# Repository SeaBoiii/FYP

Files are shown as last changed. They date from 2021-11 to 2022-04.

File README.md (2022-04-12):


<!--
*** Thanks for checking out the Best-README-Template. If you have a suggestion
*** that would make this better, please fork the repo and create a pull request
*** or simply open an issue with the tag "enhancement".
*** Don't forget to give the project a star!
*** Thanks again! Now go create something AMAZING! :D
-->

<!-- PROJECT SHIELDS -->
<!--
*** I'm using markdown "reference style" links for readability.
*** Reference links are enclosed in brackets [ ] instead of parentheses ( ).
*** See the bottom of this document for the declaration of the reference variables
*** for contributors-url, forks-url, etc. This is an optional, concise syntax you may use.
*** https://www.markdownguide.org/basic-syntax/#reference-style-links
-->
[][issues-url]
[][license-url]
[][linkedin-url]

<!-- PROJECT LOGO -->
<br />
<div align="center">
  <a href="https://github.com/SeaBoiii/FYP">
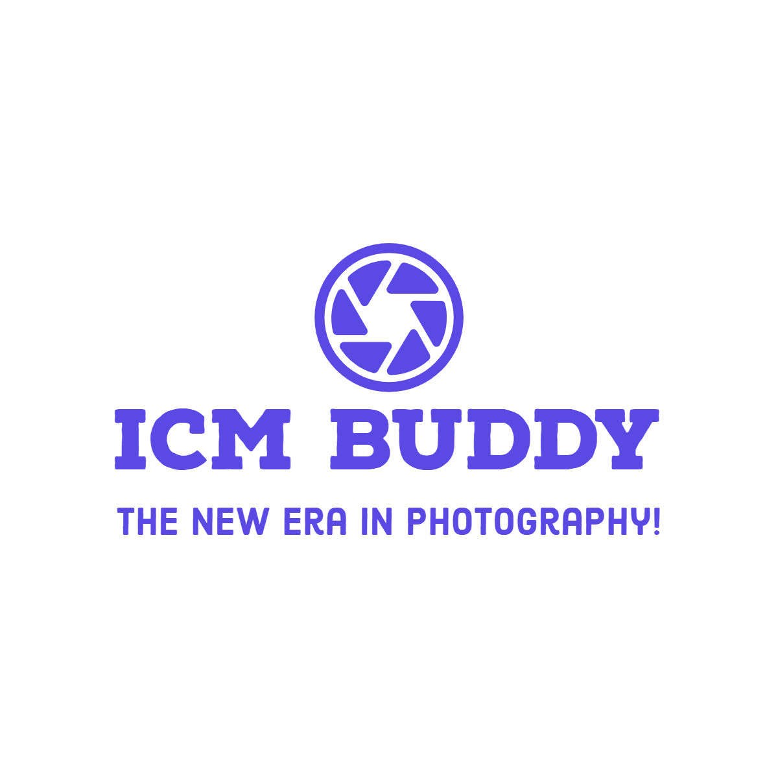
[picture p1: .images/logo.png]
    
  </a>

<h3 align="center">ICM Buddy</h3>

  <p align="center">
    The projective objective is to improve the user experience for experienced and new photographers by providing automation to the camera during the long exposure shoot.
    <br />
    <a href="https://github.com/SeaBoiii/FYP/blob/main/.documents/ICM_Buddy_Final_Report.pdf"><strong>Explore the docs »</strong></a>
    <br />
    <br />
    <a href="https://www.youtube.com/watch?v=y02GOHybE4I">View Demo</a>
    ·
    <a href="https://github.com/SeaBoiii/FYP/issues">Report Bug</a>
    ·
    <a href="https://github.com/SeaBoiii/FYP/issues">Request Feature</a>
  </p>
</div>

<!-- TABLE OF CONTENTS -->
<details>
  <summary>Table of Contents</summary>
  <ol>
    <li>
      <a href="#about-the-project">About The Project</a>
      <ul>
        <li><a href="#built-with">Built With</a></li>
      </ul>
    </li>
    <li>
      <a href="#getting-started">Getting Started</a>
      <ul>
        <li><a href="#prerequisites">Prerequisites</a></li>
        <li><a href="#installation">Installation</a></li>
      </ul>
    </li>
    <li><a href="#usage">Usage</a></li>
    <li><a href="#contributing">Contributing</a></li>
    <li><a href="#contact">Contact</a></li>
    <li><a href="#acknowledgments">Acknowledgments</a></li>
  </ol>
</details>

<!-- ABOUT THE PROJECT -->
## About The Project

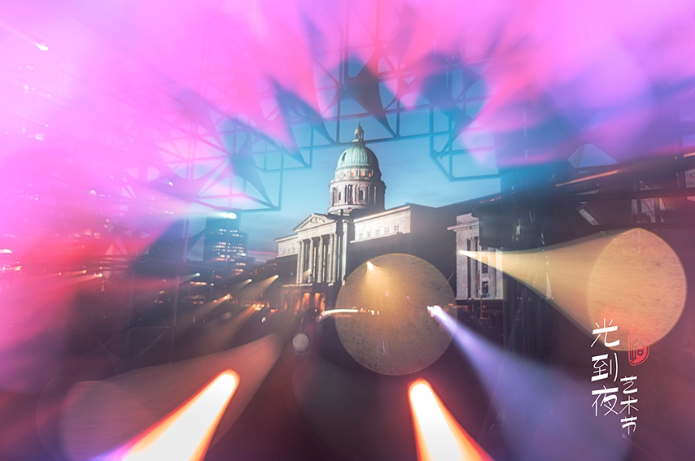
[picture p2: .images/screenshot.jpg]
Product Name Screen Shot


This project aims to improve the consistency of the results obtained from long exposure photography and present new ways to take slow exposure photos by automating the movements of the focus and zoom lens during the shoot. With the pre-sets available in the project, photographers will be able to control the type of resulting images that they can get. 

This project was designed and implemented to produce a system capable in conducting a long exposure shoot with unique sequences to get the optimal long-exposure image results. Through the integration of hardware and software, high precision, and consistency of the DSLR lens rotation could be achieved. This unfolds an endless possibility for both experienced and aspiring photographers in long exposure photography.

From the confident results gathered during testing, this project can produce a consistent and repeatable long exposure image. Paired with the various patterns extended with the custom pattern that user can input, various beautiful long exposed images can be taken.

<p align="right">(<a href="#top">back to top</a>)</p>

### Built With

* [Arduino](https://www.arduino.cc/)

#### Hardware Required
| Name | Quantity | Description |
| --- | ---| ---|
| Arduino Nano | 1 | Small ATmega328 microcontroller 
| TMC2208 Stepper Driver | 2 | Ultra-quiet two-phase stepper motor drive chip, to drive the stepper motors | | |
| NEMA 17 Stepper Motor | 2 | High torque motors to provide precision movements of the lens | | |
| Buzzer | 1 | Sound indicator for users to know before and after a certain sequence is executed | | |
| 1.8’ TFT Display | 1 | Menu selector to control the lens | | |
| Optocoupler P627 | 1 | Isolates the circuit from the camera shutter. Prevents damaging the circuit by high current when the camera shutter is triggered. | | |
| 2.5mm Jack | 1 | Connector for DSLR Camera’s shutter | | |
| 5 Pin Joystick | 1 | Menu movements to select the different options in the menu | | |
| 220 Ω Resistor | 5 | Limit the current to the TFT display | | |
| 1k Ω Resistor | 1 | Limit the current to the Optocoupler | | |
| 100 µF Capacitor | 1 | Prevents accidental damage to the drivers in case of current surge | | |
| 11.1V Lipo Battery | 1 | Power supply for the entire hardware | | |
| DSLR Camera | 1 | For capturing the long exposure images | | |
| Arca-Type compatible DSLR rail | 1 | Motors can be mounted along the rail | | |
| 0.8 Mod Gear Rings | 2 | Rings attached to the focus & zoom lens | | |
| KW12-3 Limit Switch | 4 | [Optional] For further control to the lens | | |

<p align="right">(<a href="#top">back to top</a>)</p>

<!-- GETTING STARTED -->
## Getting Started

The first thing that you will have to do is to create the same setup. The same setup, can be done using the circuit diagram found in the folder. All the hardware required were mentioned above. 

<a href="https://github.com/SeaBoiii/FYP">
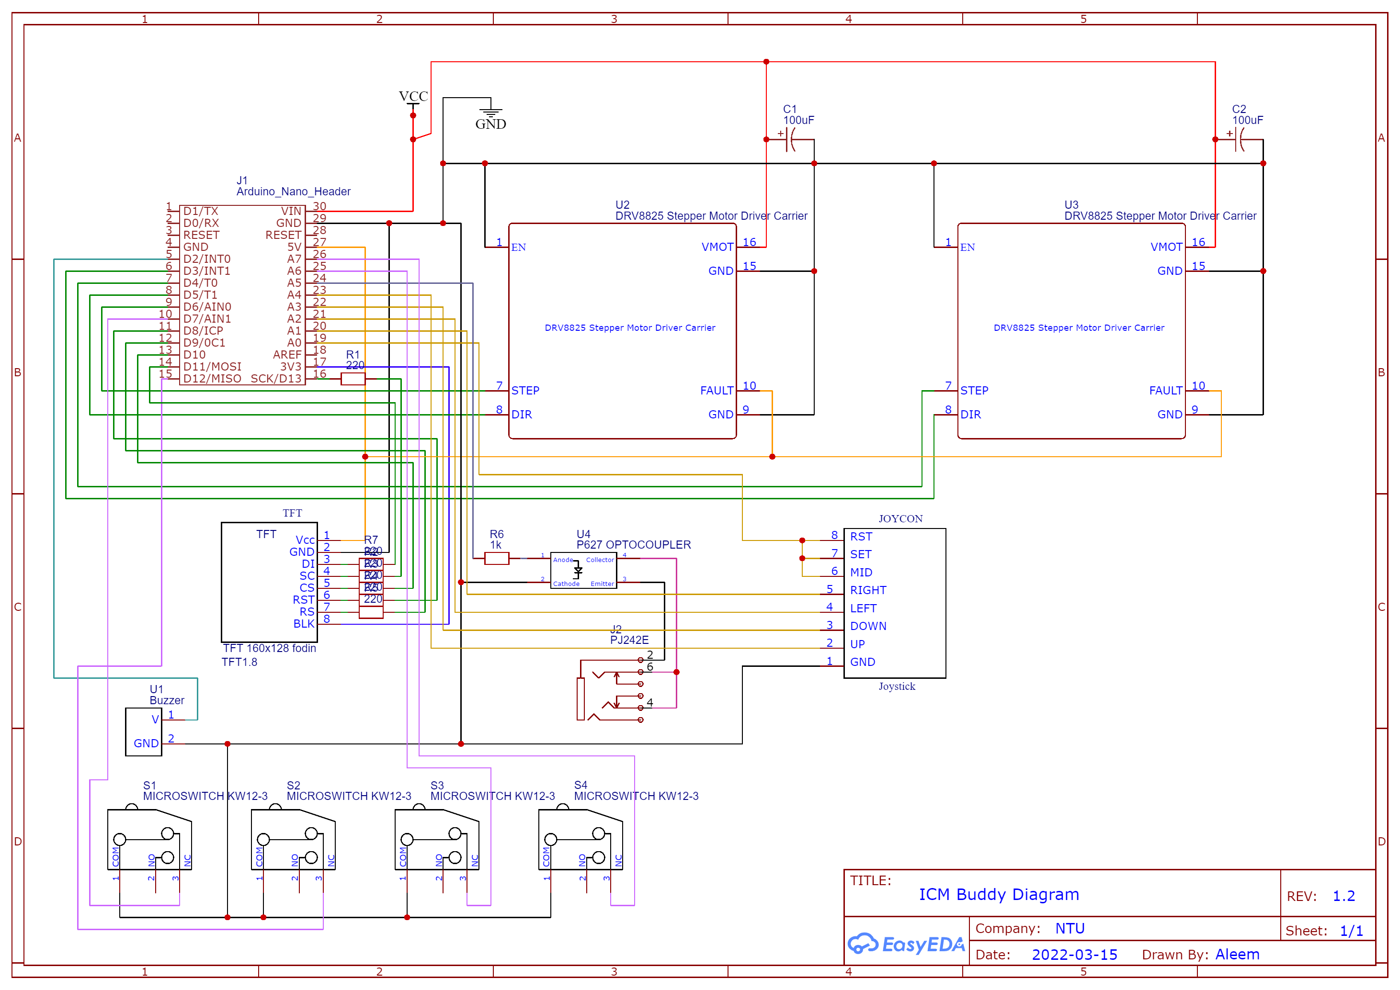
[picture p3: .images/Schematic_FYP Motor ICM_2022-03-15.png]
Schematic Diagram
    
  </a>

If creating the board is to tedious, you can always print a PCB for easier replica of the project. The details of the PCB can be found at [PCB Designs](https://github.com/SeaBoiii/FYP/tree/main/.3D_Designs/PCB).

### Prerequisites

The only software requirement is the Arduino IDE to flash the program to the Arduino. 
* [Arduino](https://www.arduino.cc/en/Guide)

#### Libraries Used

All the libraries used can be downloaded using the IDE or downloaded manually and dropped to the library folder. Only the `AccelStepper` library required to be downloaded while the rest of the library should be pre-installed in the Arduino IDE.
* [AccelStepper](https://www.airspayce.com/mikem/arduino/AccelStepper/)
* [TFT](https://www.arduino.cc/reference/en/libraries/tft/)
* [EEPROM](https://docs.arduino.cc/learn/built-in-libraries/eeprom/)

### Installation

1. Build the prototype first
2. Clone the repo
   ```sh
   git clone https://github.com/SeaBoiii/FYP.git
   ```
3. Install required Arduino libraries
   ```sh
   arduino install AccelStepper
   ```
4. Upload Motor_ICM.ino to the Arduino Microcontroller
   ```sh
   upload Motor_ICM.ino
   ```

<p align="right">(<a href="#top">back to top</a>)</p>

<!-- USAGE EXAMPLES -->
## Usage

The menu of the prototype is very intuitive and navigation can be done smoothly. After attaching the device to your lens, the 1st thing that you would want to do is `calibration`. This allows the motors to remember the marked locations to prevent any damages to the lens. Explore the various menus and patterns available by default to generate interesting long exposure images. 

If the installed patterns are not to your liking, feel free to edit the code and change it or even use the inbuilt custom patterns to build your own custom patterns. Here are more examples of what this device is capable of.

<a href="https://github.com/SeaBoiii/FYP">
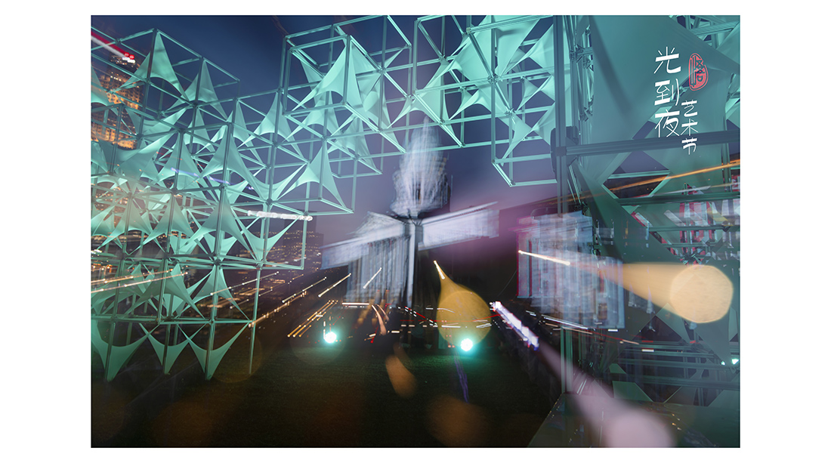
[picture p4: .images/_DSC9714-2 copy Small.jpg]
Using a certain pattern 1
    
</a>

<p align="center">
Using both the movements of the focus and the zoom lens, this shot was taken at the Old Supreme Court building in Singapore.
</p>
  
<a href="https://github.com/SeaBoiii/FYP">
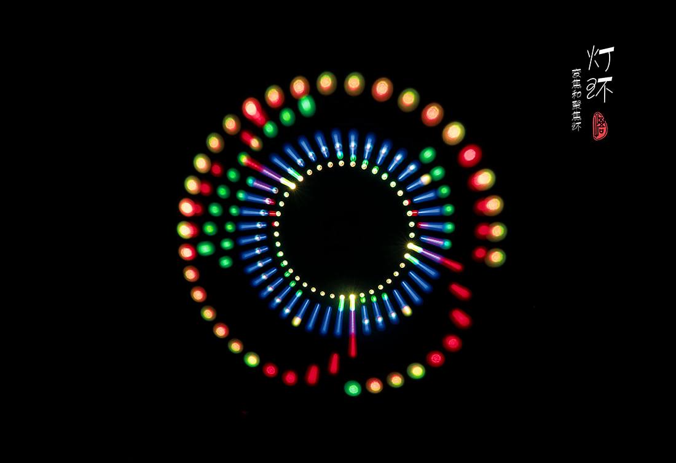
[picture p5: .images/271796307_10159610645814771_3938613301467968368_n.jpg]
Using a certain pattern 2
    
</a>

<p align="center">
Again, both the focus and zoom lens were used to create a circular motion effect of lights. 
</p>
  
<a href="https://github.com/SeaBoiii/FYP">
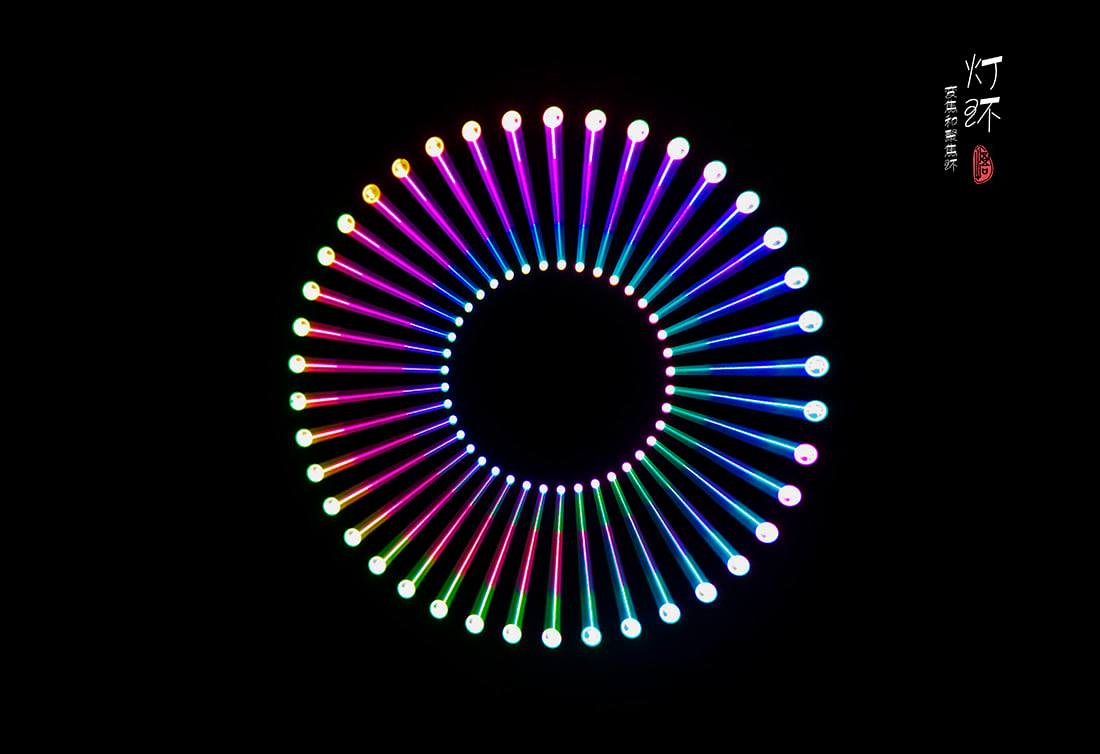
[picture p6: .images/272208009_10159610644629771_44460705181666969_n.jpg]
Using a certain pattern 3
    
</a>

<p align="center">
Only the zoom lens were moved here to create a tunnel vision look.
</p>
  
_For more examples, please refer to the [Documentation](https://github.com/SeaBoiii/FYP/blob/main/.documents/ICM_Buddy_Final_Report.pdf)_

<p align="right">(<a href="#top">back to top</a>)</p>

<!-- CONTRIBUTING -->
## Contributing

Contributions are what make the open source community such an amazing place to learn, inspire, and create. Any contributions you make are **greatly appreciated**.

If you have a suggestion that would make this better, please fork the repo and create a pull request. You can also simply open an issue with the tag "enhancement".
Don't forget to give the project a star! Thanks again!

1. Fork the Project
2. Create your Feature Branch (`git checkout -b feature/AmazingFeature`)
3. Commit your Changes (`git commit -m 'Add some AmazingFeature'`)
4. Push to the Branch (`git push origin feature/AmazingFeature`)
5. Open a Pull Request

<p align="right">(<a href="#top">back to top</a>)</p>

<!-- CONTACT -->
## Contact

Project Link: [https://github.com/SeaBoiii/FYP](https://github.com/SeaBoiii/FYP)

	




<p align="right">(<a href="#top">back to top</a>)</p>

<!-- ACKNOWLEDGMENTS -->
## Acknowledgments

* A/P Chia - My FYP mentor, someone who helped me throughout the whole project
* Auntie @ SimLim Tower - For providing any extra hardware required for my own testings

<p align="right">(<a href="#top">back to top</a>)</p>

<!-- MARKDOWN LINKS & IMAGES -->
<!-- https://www.markdownguide.org/basic-syntax/#reference-style-links -->
[contributors-shield]: https://img.shields.io/github/contributors/SeaBoiii/FYP.svg?style=for-the-badge
[contributors-url]: https://github.com/SeaBoiii/FYP/graphs/contributors
[forks-shield]: https://img.shields.io/github/forks/SeaBoiii/FYP.svg?style=for-the-badge
[forks-url]: https://github.com/SeaBoiii/FYP/network/members
[stars-shield]: https://img.shields.io/github/stars/SeaBoiii/FYP.svg?style=for-the-badge
[stars-url]: https://github.com/SeaBoiii/FYP/stargazers
[issues-shield]: https://img.shields.io/github/issues/SeaBoiii/FYP.svg?style=for-the-badge
[issues-url]: https://github.com/SeaBoiii/FYP/issues
[license-shield]: https://img.shields.io/github/license/SeaBoiii/FYP.svg?style=for-the-badge
[license-url]: https://github.com/SeaBoiii/FYP/blob/master/LICENSE.txt
[linkedin-shield]: https://img.shields.io/badge/-LinkedIn-black.svg?style=for-the-badge&logo=linkedin&colorB=555
[linkedin-url]: https://linkedin.com/in/a1e3m
[product-screenshot]: .images/screenshot.jpg

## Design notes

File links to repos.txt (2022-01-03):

http://www.airspayce.com/mikem/arduino/AccelStepper/classAccelStepper.html
https://www.electronics-lab.com/project/using-st7735-1-8-color-tft-display-arduino/
https://learn.adafruit.com/1-8-tft-display/breakout-wiring-and-test
https://github.com/XarkLabs/PDQ_GFX_Libs

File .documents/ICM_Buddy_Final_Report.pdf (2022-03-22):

School of Computer Science and Engineering

## Final Year Project

## Final Report

## SCSE21-0384: ICM Buddy – Zoom/Focus Assist Tool

Supervisor: A/P Chia Liang Tien

Examiner: Ast/P Lin Shang-Wei

Submitted by: Aleem Siddique Bin Abdul Jamal

Matriculation Number: U1821548E

## NANYANG TECHNOLOGICAL

## UNIVERSITY

# SCSE21-0384: ICM Buddy – Zoom/Focus Assist Tool

## Submitted in Partial Fulfilment of the Requirements for the Degree of

## Bachelor of Computer Engineering of the Nanyang Technological

## University

By

## ALEEM SIDDIQUE ABDUL JAMAL

## Abstract

Long exposure photography is a technique of capturing an image for extended periods of time

to get unique moments, in moving lights photography. There are few commercialised kits

related to long exposure photography sold in the market. And most of these kits are not easily

customisable, or any available automated pre-sets pre-installed. Long exposure photography

can be very tedious to set up since a lot of knowledge of moving the zoom and focus lens during

the shoot will give varying result. Though long exposure shoots can be a fun experience

available to all ages, it requires a lot of time and precision to get the image they want.

This project aims to improve and extend the functionality relating to long exposure

photography that involves the movements of the zoom and focus lens during the exposure

period. The focus of the project is to engineer a prototype capable of bringing automation to

the DSLR cameras during the long exposure shoots by swivelling the zoom and focus lens

utilising motors.

Long exposure photography can be achieved easily with the integration of hardware and

software on Arduino used in this project.

## Acknowledgement

I would like to thank my supervisor, A/P Chia Liang Tien for his guidance and support

throughout the entire course of this final year project. His extreme knowledge in hardware and

his advice has helped me progress through the project without much hiccups.

I would also like to thank the lab attendants from the Software Project Labs for their assistance

in loaning equipment especially the soldering equipment during the soldering process of this

project.

Lastly, I want to thank my friends for their support and suggestions to improve especially the

software part of the project.

## Table of Contents

## Table of Figures

## List of Tables

## List of Abbreviations and Symbols

Abbreviation/Symbols | Description
DSLR | Digital Single Lens Reflex
ISO | International Organization for Standardization
GUI | Graphical User Interface
UI | User Interface
PCB | Printed Circuit Board
TFT | Thin Film Transistor
NEMA | National Electrical Manufacturers Association
3D | Three-Dimensional
LCD | Liquid Crystal Display
CAD | Computer-Aided Design
POV | Point of View
mm | Millimetre, unit measurement for lengths
Ω | Ohm, unit measurement for resistor
µF | Micro farad, unit of measurement for capacitor
° | Degree, unit of measurement for angle

## 1. Introduction

1.1 Background

Long exposure photography, also known as slow exposure, is one of the many types of DSLR

photography. Long Exposure photography is usually use by photographers to capture objects

in motion or static objects with a moving background for long periods of time [1].

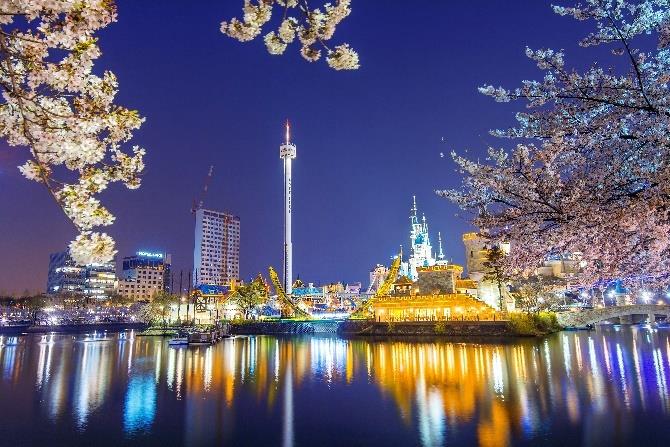
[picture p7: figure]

Figure 1: Long exposure image of traffic [2] | Figure 2: Long exposure image of lights at night [3]

Both process of photography requires time in scouting the area, setting up the equipment as

well as multiple tries to get the desired image. A lot of calculations are also necessary in terms

of the camera settings such as the shutter speed, the ISO, and others [4]. Furthermore, humans

are inconsistent, and this will result in extra time needed to get a consistent result that

photographers are satisfied [5]. The experimentation required during a long exposure shoot is

extremely tedious and there is no straightforward approach available to get pleasurable photos.

This applies to not only experienced photographers but even new aspiring photographers who

wants to learn about long exposure photography will stay away due to the exhausting process

and inconsistent results.

1.2 Project Objective

This project aims to improve the consistency of the results obtained from long exposure

photography and present new ways to take slow exposure photos by automating the movements

of the focus and zoom lens during the shoot. With the pre-sets available in the project,

photographers will be able to control the type of resulting images that they can get. The

projective objective is to improve the user experience for experienced and new photographers

by providing automation to the camera during the long exposure shoot.

1.3 Project Scope

The followings are the scope of the project:

1. Research on long exposure photography, for objects in motion as well as static objects.
2. Research on available motor types to turn the camera lens.
3. Build a prototype (hardware) to control the lens through Arduino
a. Decide on the motor & Arduino to be used for the project
b. Have a display & joystick to efficiently control the different lens, zoom & focus

lens.

c. Code (software) on the Arduino to integrate the hardware together
4. Implement functionalities for the Arduino
a. Create different pre-sets or ways to control the movement of the lenses.
b. Effortlessly allow users to get a long exposure image with a click of a button

and a simple GUI.

## 2. Literature Review

2.1 Long Exposure Photography

Long exposure photography is a type of photography art in capturing an image where stationary

element are sharp while moving elements are smeared. Photographers normally use exposure

photography to capture a certain view like the stars. The main settings for long exposure shots

are the shutter speed, ISO, and the aperture of the DSLR camera [6].

2.1.1 Setting Up

The set-up for a long exposure shoot is simple. Other than the camera settings that requires to

be experimented, a lot of scouting is required in finding a great area to work in. Furthermore,

the use of a tripod is important for a good exposure photo as it keeps the DSLR camera from

moving around like from strong winds, during the shoot.

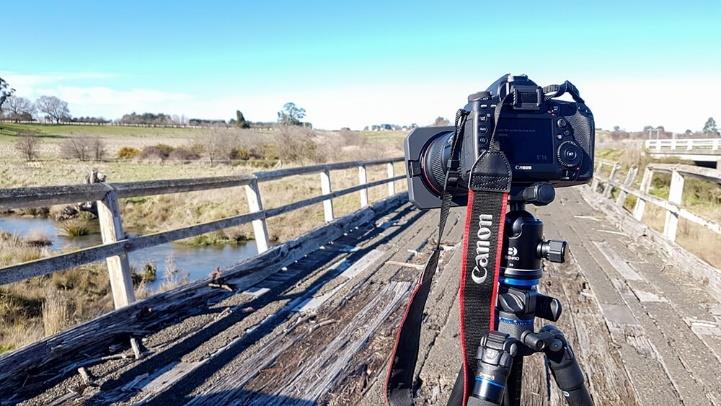
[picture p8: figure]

Figure 3: A setup of a long exposure shoot [7]

After applying the necessary camera settings, the photographer than starts the slow exposure

photograph by pressing the shutter. After the shutter speed set, the DSLR camera will close the

shutter and a long-exposed image will be shown.

2.1.2 The ‘Standard’ Procedure

Ordinarily, long exposure photography involves the DSLR camera being still, and the lens

should not move during the exposure. The lens is normally related to the sharpness of the

image, and disrupting the setup during an exposure shoot, will affect it. However, there are

instances where moving the lens during an exposure will get a particular type of effect. Quoted

by Joe McNally, “Moving the lens during the shoot may seem like a dangerous thing but it can

be kind of a fun thing to do.” [8] By rotating the lens during an exposure, many different types

of outcomes can occur which will be further explored in this project.

2.1.3 Camera Settings

The main camera setting that affect long exposure photography are mainly shutter speed.

Normally, during a long exposure photography session, only the shutter speed setting is

tweaked while the ISO and aperture remains untouched.

Shutter Speed

Shutter speed refers to the time for the camera shutter to stay open and expose the DSLR

camera sensor to light [9]. For long exposure photography, this setting is normally set to a low

shutter speed to capture more details and changes to the light.

Shutter Speed | Photo Clarity
Fast | Darker picture and less blur
Slow | Brighter picture but more blur

Table 1: Relationship between shutter speed and photo clarity

2.2 Follow Focus Gears

The follow focus gears were created to have finer controls over the DSLR focus adjustments.

This prevents the photographer from focusing to the wrong subject. Follow focus is normally

used in filmmaking with film cameras as it helps the operator to be more efficient and precise.

Figure 4: Fotga’s DP500II2 follow focus unit [10]

Though their usage was meant to be used in videos for accurate focus control, the possibility

of rotating the lens can be applied elsewhere, in the example of long exposure photography.

By rotating both the zoom and the focus lens, photographers can get a whole new dimension

in long exposure photography.

## 3. Project Planning

3.1 Material/Equipment Resources (Hardware)

The hardware resources used in this project are shown in Table 1.

Name | Quantity | Description
Arduino Nano | 1 | Small ATmega328 microcontroller
TMC2208 Stepper Driver | 2 | Ultra-quiet two-phase stepper motor drive chip, to drive the stepper motors
NEMA 17 Stepper Motor | 2 | High torque motors to provide precision movements of the lens
Buzzer | 1 | Sound indicator for users to know before and after a certain sequence is executed
1.8’ TFT Display | 1 | Menu selector to control the lens
Optocoupler P627 | 1 | Isolates the circuit from the camera shutter. Prevents damaging the circuit by high current when the camera shutter is triggered.
2.5mm Jack | 1 | Connector for DSLR Camera’s shutter
5 Pin Joystick | 1 | Menu movements to select the different options in the menu
220 Ω Resistor | 5 | Limit the current to the TFT display
1k Ω Resistor | 1 | Limit the current to the Optocoupler
100 µF Capacitor | 1 | Prevents accidental damage to the drivers in case of current surge
11.1V Lipo Battery | 1 | Power supply for the entire hardware
DSLR Camera | 1 | For capturing the long exposure images
Arca-Type compatible DSLR rail | 1 | Motors can be mounted along the rail
0.8 Mod Gear Rings | 2 | Rings attached to the focus & zoom lens
KW12-3 Limit Switch | 4 | [Optional] For further control to the lens

Table 2: Hardware Resources

The connection guide for the hardware can be seen in Appendix A.

3.2 Material/Equipment Resources (Software)

Name | Description
Arduino IDE | Official IDE for Arduino microcontroller software development
AccelStepper Library | Arduino Library by Mike McCauley maintained by Patrick Wasp to control the motor drivers
TFT Library | Arduino Library that enables communication with the Arduino TFT LCD screen
SPI Library | Arduino Library that enables communication with SPI devices
Program Space Utilities | Arduino Library for interfacing with the flash memory of the Arduino
EEPROM Library | Arduino Library for interfacing with the memory of the Arduino
OpenSCAD | A 3D CAD software to create 3D objects for 3D printing
EasyEDA | Software used for PCB designing and circuit diagram creation

Table 3: Software Resources

3.3 Project Process Model

This project follows the linear-sequential life cycle model or approach. The project is separated

into small parts such as motor movements phase, GUI phase, assessed before integrating

together during the testing phase of the model. This ensures tasks are easily arranged and

rigorously evaluated before proceeding to the next phase [11]. Overall, ensuring the project

development to be completed on time and well documented.

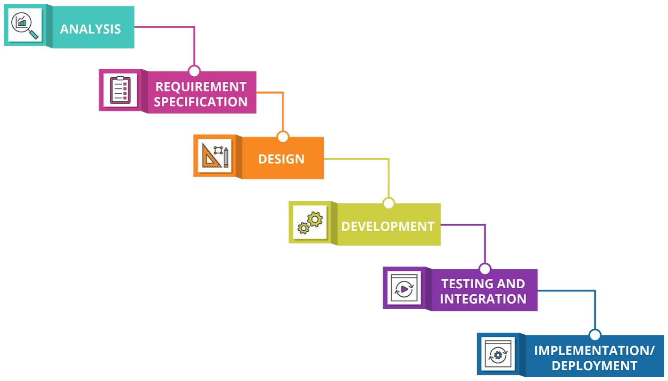
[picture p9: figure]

Figure 5: Waterfall Model [12]

3.4 Project Schedule

The initial project’s timeline is shown below.

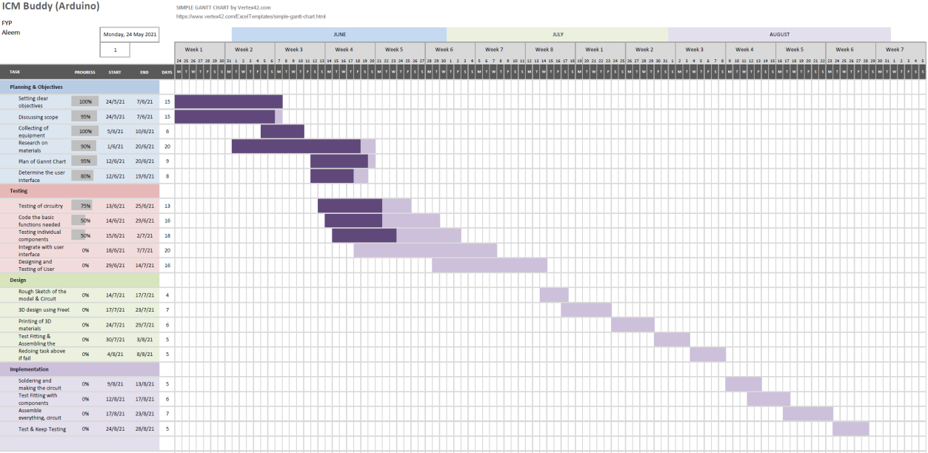
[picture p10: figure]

Figure 6: Initial Gantt Chart

Using the model mentioned in 3.3 Project Process Model, this was the initial deadlines for the

separate phases from the Waterfall Model approach. However, due to some errors and

insufficient research done, the project deviated from the original deadline. This will be further

discussed in (insert heading). The project’s updated timeline is shown in Table 3.

Task Description | Start Date | End Date | Duration (Days)
Discussing scope | 24/5/2021 | 7/6/2021 | 15
Research on long-exposure photography | 1/6/2021 | 20/6/2021 | 20
Research on different motors | 1/6/2021 | 20/6/2021 | 20
Collecting of equipment | 5/6/2021 | 10/6/2021 | 6
Testing of individual components (Circuitry) | 21/6/2021 | 10/7/2021 | 19
Testing of individual components (Software) | 11/7/2021 | 25/7/2021 | 14
3D Design of components required (gears, bases, case, etc.) | 26/7/2021 | 31/7/2021 | 5
Printing of 3D components | 31/7/2021 | 3/8/2021 | 3
Integrating the individual components together | 4/8/2021 | 10/8/2021 | 7
Test fitting and assembling the circuitry | 11/8/2021 | 13/8/2021 | 3

Testing of the integrated module | 14/8/2021 | 18/8/2021 | 5
Testing failed which results in repeating the tasks again as there is a change in the motor used | 19/8/2021 | 7/9/2021 | 20
Integrating and evaluating the integrated module again | 8/9/2021 | 16/9/2021 | 8
Testing failed again, which results in more research needed and a change of hardware again | 17/9/2021 | 27/9/2021 | 10
Revision and Examination | 28/9/2021 | 9/10/2021 | 12
Update & print 3D designs to combat the previous failed testing | 10/10/2021 | 23/10/2021 | 13
Redo the circuitry (hardware) components & testing of integrated module | 24/10/2021 | 13/11/2021 | 21
Revision and Examination | 16/12/2021 | 5/12/2021 | 15
Testing of integrated module | 7/12/2021 | 21/12/2021 | 14
Improvements to GUI | 22/12/2021 | 6/1/2022 | 16
Improvements to code stability | 7/1/2022 | 21/1/2022 | 14
Documentation of code | 22/1/2022 | 25/1/2022 | 4
PCB designing | 26/1/2022 | 30/1/2022 | 5
Improvements to 3D designed components to improve overall stability | 1/2/2022 | 10/2/2022 | 11
Tidying of code | 11/2/2022 | 26/2/2022 | 15
Revision and Examination | 1/3/2022 | 12/3/2022 | 12
PCB printing & soldering of components to PCB | 7/3/2022 | 14/3/2022 | 7
Final Year Project Report | 5/3/2022 | 21/3/2022 | 17
Revision and Examination | 19/4/2022 | 7/4/2022 | 15
Oral Presentation | 10/5/2022 | 10/5/2022 | 1

Table 4: Project's Updated Timeline

## 4. Design Documentation

4.1 Design

Two separate designs with the same functionality were prototyped for this project. Both circuits

use the same microcontroller, the “Arduino Nano” supporting the basic functionalities of

Arduino SOC.

Figure 7: Arduino Nano used for the project [13]

The core components of the two designs were the 3D Printed components such as gears & the

motor housing and the type of motor used. The main prototype that this report will be

discussing is the prototype that used stepper motors. The circuit diagram for the main prototype

can be found in Appendix A. Figure 8 highlighted the whole setup excluding the DSLR camera

that was to be mounted on the Arca-Type compatible DSLR rail.

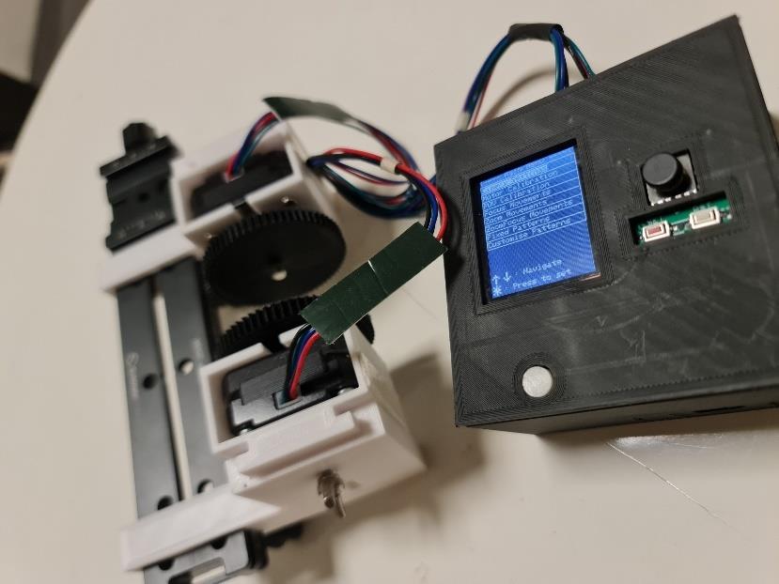
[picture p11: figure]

Figure 8: Setup using Stepper Motors

The prototype that used servo motors was an additional add-on to experiment whether different

motors would vary the movement of the lens. The circuit diagram for the servo motor prototype

can be found in Appendix B.

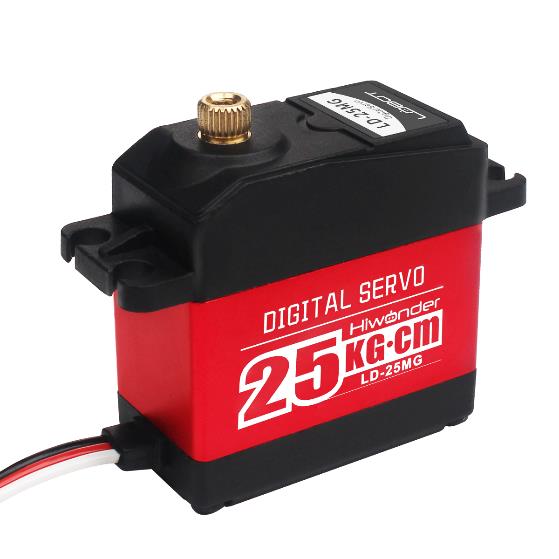
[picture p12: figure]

Figure 9: Hiwonder 25kg Servo Motor used

in the servo-based prototype [14]

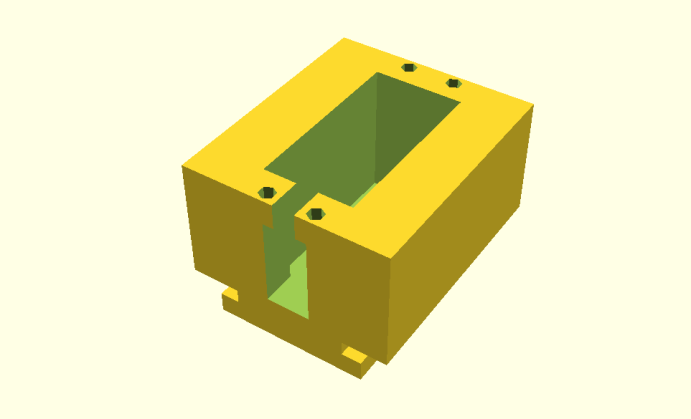
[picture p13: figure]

Figure 10: 3D CAD of the motor housing used for the servo

motors

With the different motors used for both prototypes, this resulted various changes to the 3D

components used since there is a change of dimension for the motor housings & gears.

Other than hardware components, an important research factor that I had to keep in mind during

the designing process was torque. Torque is “a force that causes something to rotate,” as quoted

from Cambridge Dictionary [15]. In this project, a certain amount of torque is required for the

motor to be able to rotate the lens. The variables that determining factors for torque in this

project were the size of gears, the type & size of motor used and the rigidity of the 3D printed

motor mounts.

4.1.1 3D CAD components

The 3D printed components were one of the key components for the project. The measurements

had to be precise, especially the incisions for the screw holes, the T-Slot track, down to less

than a millimetre in precision. The main 3D components that were necessary for the prototype

to function were the T-Slot base, the gears as well as the motor housing. No 3D printed part

for the lens were necessary as there were already plenty of aftermarket choices. These gear

rings will only be needed if the lens lacks a 0.8 module gear to rotate it.

Figure 11: The gear rings used that were attached to the zoom & focus part of the lens

Due to the nature of 3D designing, a lot of pre-sketching of the designs were required to have

a gist of how the 3D object would look like. In addition, 3D printing the components took

plenty of time, combined with the availability of 1 3D printer, courtesy of my Professor, Prof

Chia. Hence, some of the 3D printings were printed by external vendors.

Figure 12: Sketches of the 3D components with measurements

The main software that I used during the 3D CAD objects was OpenSCAD, a script-based

CAD software.

4.1.1.1 T-Slot Base Mount

The design ideology behind the requirement of a T-Slot was the need of an adjustable height

requirement for the motor due to the assorted sizes of available DSLR lens. The T-Slot

functioned as a means of secure for the height of the motor housing to be adjusted.

However, standardised, T-Slots had a very much complex design and to integrate it to the

project, it would be too tedious and time consuming. Therefore, a much simpler design was

needed to provide the same functionality as the traditional T-Slots, the rail like movement as

well as the means of securement. Unlike traditional T-Slot rails, also called OpenBeam, where

it has 4 T-slots available, the design only required one, and a simpler T-shape is needed rather

than the complex trapezium shape from most standardised rails.

Figure 14: Standardised/Traditional T-Slot rail [16]

Screw to secure the
motor housing in
place to a certain
height

T-Slot rail for
the height of
the motor to be
adjustable

Figure 13: The motor housing secured to the T-Slot base

As for the base of the T-Slot, it was designed as an Arca-Type compatible mount, where it can

slide onto any slides that are Arca-Type compatible. Depending on the length of the lens,

different length of the slides is required for the base mount to be fitly secured to the gear rings

on the lens. A lot of iterations of the base mount was required due to the inexperience of 3D

modelling in addition to the strength testing requirement to keep the motor in place when it

was rotating.

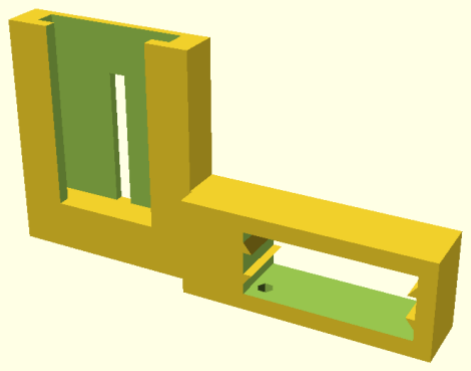
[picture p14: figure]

Figure 15: 3D render of the final iteration of the base mount

Since OpenSCAD is a script-based software, the 3D design of the base mount was not as

tiresome and not including any complex shapes made the process simpler. A code snippet can

be seen below.

module t_slot_beam(t_length, t_thickness) { slot_length = t_length;
slot_thickness = t_thickness; padded_width = mount_width+thickness*2;

difference() {
// stuff to build up
union() {
cube([padded_width, slot_thickness, slot_length]); }
// things to cut out (The T-Slot shaped) t_slot_length = 3;
t_slot_width = 15+20;
t_slot_thickness = 6+20;

translate([padded_width/2-(t_slot_thickness/2),0, 0]) cube([t_slot_thickness, t_slot_length, slot_length]);

translate([padded_width/2-(t_slot_width/2),t_slot_length, 0])
cube([t_slot_width, thickness+3, slot_length]);

translate([padded_width/2-(4/2),t_slot_length+thickness+3,slot_length/2-padded_width/2]) cube([4,2,slot_length-10.5]);
}
}

Figure 16: Code snippet of creating a T-Slot

As seen from the code snippet, to render the 3D object, it was with a simple function call. The

length and thickness of the T-Slot can be adjusted easily by changing the required parameters.

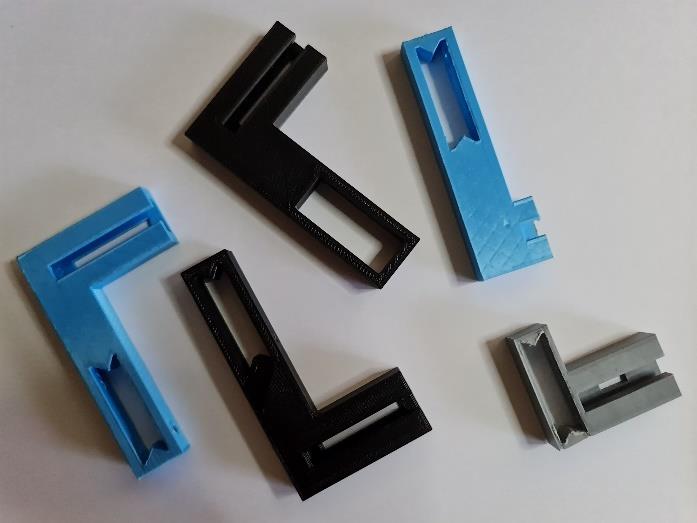
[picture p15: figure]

Figure 17: Different iterations of the base mount

Even then, a lot of effort was required when evaluating the bases to keep the motor in place

during rotation along with being sturdy. Changes to the thickness, the T-Slot size were required

to get the ideal amount of rigidity and sturdiness to prevent the motor from shaking during the

lens rotation.

4.1.1.2 Gears

Gears were also the main components of the entire system. The gears were used to turn the lens

of the DSLR camera. Through research, the size of the gears was important as they determine

the overall torque of the motors, as mentioned previously. The 3D models for the gears were

made with the use of a library created by Thingiverse user eleotlecram. It had a simple GUI to

generate & render the gears.

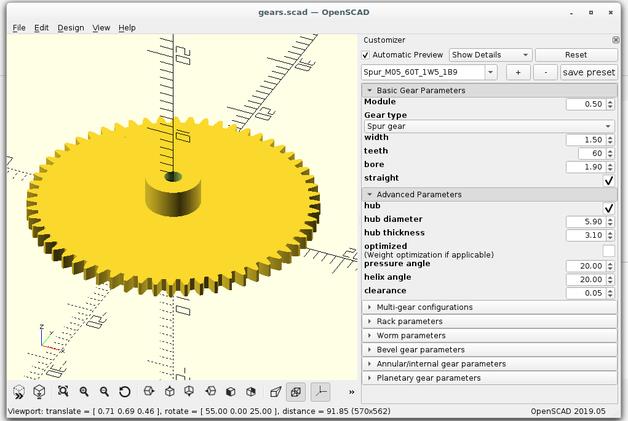
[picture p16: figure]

Figure 18: Gear library used with an intuitive customizer

The type of gear used was the basic 0.8 module spur gears; most DSLR gear rings are 0.8

module as described then. The only variable changed was the number of teeth of the gear (also

corresponds to the size of the gear). The relationship between the number of teeth of a gear and

the torque of the motor as well as the maximum degree of rotation of the lens.

Number of teeth of gear | Torque of motor | Degree of rotation of lens
More (Bigger gear) | Greatly reduced | Increased
Less (Smaller gear) | Increased | Reduced

Table 5: Relationship of the size of gear

Therefore, consideration towards the size of gear was considered to balance between the torque

and the degree of rotation. Most importantly, the size of the gear had to be slightly bigger than

the size of the motor housing to be able to rotate freely.

4.1.1.3 Motor Housing

The design for the motor housing was simple as the components for the housing were just the

motor encasing with a T-Slot attach to it. With the T-Slot, the motor housing would be able to

slide on the T-Slot rail on the base mount. Furthermore, the libraries made by 3D modellers

were available especially for stepper motors. The library that I used was called “Customizable

Stepper Motor Mount for OpenBeam,” which was made by ccox from Thingiverse.com. The

default motor mount was made for OpenBeam rails as shown below.

Figure 19: NEMA 17 motor mount for OpenBeam [17]

The author provided adjustable mounts from NEMA 8 to NEMA 42 motors, two of which were

used for this project: NEMA 8 & NEMA 17 motors. I had to make a few slight changes to the

model, such as covered up all the sides of the motor as well as attached the T-Slot to the back.

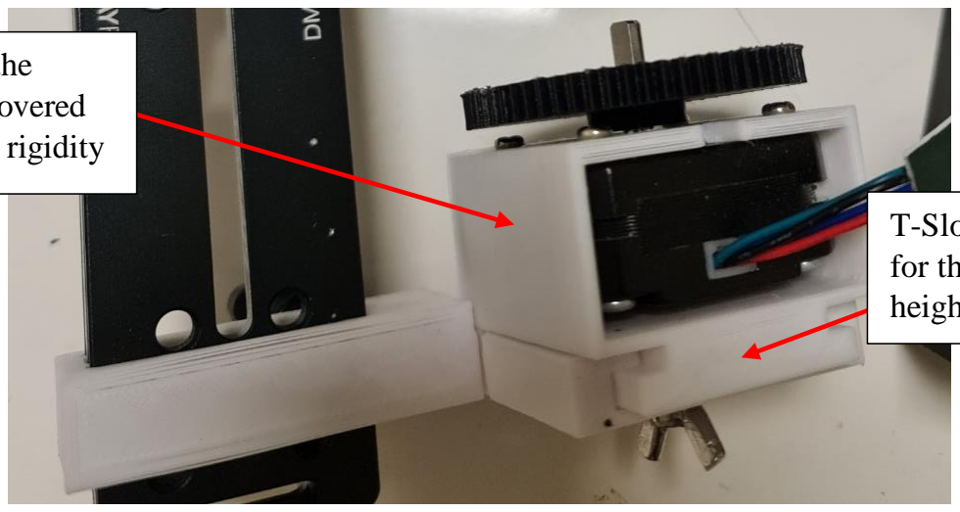
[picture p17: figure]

Figure 20: A complete 3D printed setup; the motor housing, gear & base mount

The sides of the
motor were covered
up to provide rigidity

T-Slot attached
for the adjustable
height of motor

For the servo motors, the online libraries available either were using the smaller type of servo

motors or they did not fit to the design I envisioned. Therefore, I created the servo motor mount

from scratch on OpenSCAD. The requirements for the mount: the same T-Slot as the stepper

motor mounts for hot-swappable using the same base mount & as thin in the width as possible.

difference() {
union() { | The basic cubes required for
// the base as well as the flaps | the servo motor mount
translate([0,-(padded_motor_width/4),0]) cube([padded_length,padded_motor_width,servo_height]); translate([servo_length+thickness,-(padded_motor_width/4),0]) cube([protuding_length,padded_motor_width,servo_height]); translate([-protuding_length+thickness,-(padded_motor_width/4),0]) cube([protuding_length,padded_motor_width,servo_height]);
//t slot | The same T-Slot used for stepper motor mount
xtra = 11.5;
translate([-xtra/2,(padded_width-t_slot_thickness)/2,-(t_slot_length)])
cube([padded_length+xtra,t_slot_thickness,t_slot_length]);

translate([-xtra/2, (padded_width-t_slot_width)/2, -(t_slot_length+thickness+2+0.7)]) cube([padded_length+xtra,t_slot_width,thickness+2+0.7]);
}
// **** stuff to be removed **** | Cutting a cuboid for the servo
// servo motor | motor to reside in
translate([thickness,thickness,thickness-5]) cube([servo_length,servo_width,servo_height+5]);
…

Figure 21: Code Snippet of creating the servo motor mount

There were few changes required for the motor mounts as they stayed the same throughout the

project, other than the need to change the T-Slot when the 3D components required more

rigidity to hold the torque of the motors.

4.2 Motors

For this project, two types of motors were experimented to rotate the lens, the stepper motor &

the servo motor. There were advantages and disadvantages of using either motor. Additionally,

each motor had their own considerations to follow. A list of compiled comparison between the

two types of motor can be seen in Table 6.

Stepper Motor | Servo Motor
Precision | Higher Precision – The chances of the stepper motor missing are low. | Lower Precision – The chances of the servo motor missing are higher under load.
Position Feedback | No Feedback – The stepper motor has no feature for it to know it is current position. | Feature present – Since it uses a sensor for position feedback [18], the servo motor could correct itself if it missed a step. However, this can be a problem for the project as the motor may rotate unexpectedly to correct itself in a middle of a shoot, affecting the image taken.
Torque | 4.5kg.cm | 25kg.cm
Speed of rotation | Slower | Faster
Degree of rotation | Infinite | 180° (In the case of the servo motors used for the project)
Requires a driver? | Yes | No

Table 6: Comparing features between stepper and servo motors

As seen from the table above, both motors have their strengths and weaknesses. However, the

main motor that was used for the project with its own custom PCB was the stepper motors.

4.2.1 Stepper Motor

Two models of the stepper motors, NEMA 8 and NEMA 17 stepper motors were experimented

and assessed. I started off with the smaller NEMA 8 motor before progressing to the much

larger NEMA 17 motor.

4.2.1.1 NEMA 8 Motor

NEMA 8 motors were chosen during the pre-testing phase due to the sheer small size of the

motor. Since the components had to fit the small area underneath or beside the camera.

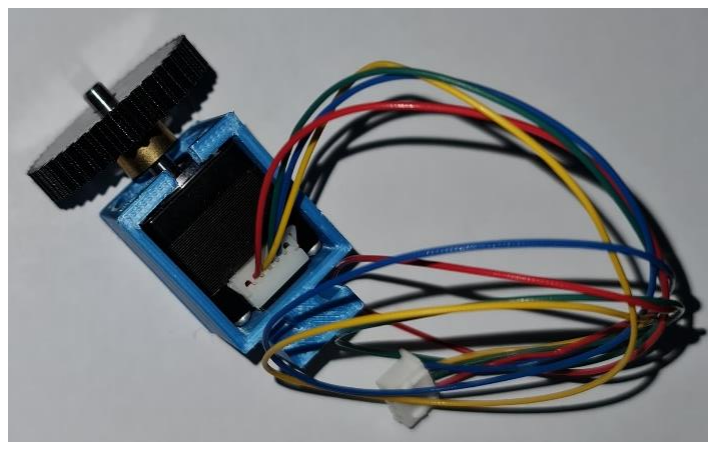
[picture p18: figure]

Figure 22: Small NEMA 8 stepper motor

However, due to the sheer size of the stepper motor, the torque of the motor was not enough to

rotate the DSLR lens, and a different motor had to be considered.

4.2.1.2 NEMA 17 Motor

Stepper motors have different lengths available for the same NEMA typed motor. In the case

of NEMA 17, there were an abundance of lengths to choose from. The “standard” length of a

NEMA 17 motor is 39mm in length. Nonetheless, this length was too big and too heavy to be

test fitted on the prototype. Therefore, a thinner NEMA 17 motor was selected and used.

Figure 23: Standard size of NEMA 17 [19] | Figure 24: NEMA 17 motor used for the project [19]

4.2.1.3 Stepper Drivers

To drive the stepper motors, a stepper driver was required. A stepper motor driver can manage

continuous rotation with precise position control [20]. Paired with a microcontroller, the driver

can rotate the stepper motors with a step and direction input. More of this will be covered in

The order of the display is as follow:

1. A countdown screen is displayed before the start of a sequence followed by a beep of

the buzzer.

2. A display of information will be displayed to the user about the current motor status.
3. If the motor must go back to its previous location, the user will be informed by the

display.

4. At the end of the sequence, a beep will be heard, signalling the end of the motor

movements.

4.3.2 Motor Control.

Two types of stepper motor drivers were evaluated, the more common A4988 stepper driver as

well as the TMC2208 driver. A comparison between the two drivers can be seen in the table

below

Figure 25: A4988 Driver | Figure 26: TMC2208 Driver
Driver chip: | A4988 | TMC2208/9
Pin Configuration: | Both the drivers have the same pin layout which made the drivers easily interchangeable with one another during testing
Noise: | Very Noisy | Quiet
Heat Generation: | With the small heatsink provided, less heat was produced | Requires a larger heatsink to combat the large amount of heat generated
Torque: | Lesser torque | Higher torque

Table 7: Comparison between the two drivers

Comparing the two drivers, the TMC2208 stepper motor driver was chosen as the final driver

to be used for the project. The quiet noise and the higher torque offsets the negligible heat

generated from the driver. A standard NEMA 17 motor requires 200 steps to rotate one round.

The TMC driver defaults to 1/8 micro stepping which suggests that a total of 8 * 200 = 1600

steps is required for 1 360° rotation.

4.2.2 Servo Motor

The servo motor used had 180° maximum rotation.

Figure 27: Servo motor used for the project [14]

Having a fixed maximum rotation suggested that I had to integrate the different components

together first because I do not have any idea on the maximum rotation for the lens. After

assessing the rotation, I concluded that the maximum rotation for any lens will always be less

than 180°.

Figure 28: The parts of the camera lens [21]

However, this was true for the zoom ring as they have a maximum and minimum rotation. For

the focus ring, some lenses do not have any maximum rotation. This issue unfortunately could

be resolved during the calibration process of the lens.

4.3 Coding/ Implementation

The programming model that was used for this project could follow procedural programming

as the software contains procedures or functions. A simple flowchart of the main loop can be

seen in the figure below.

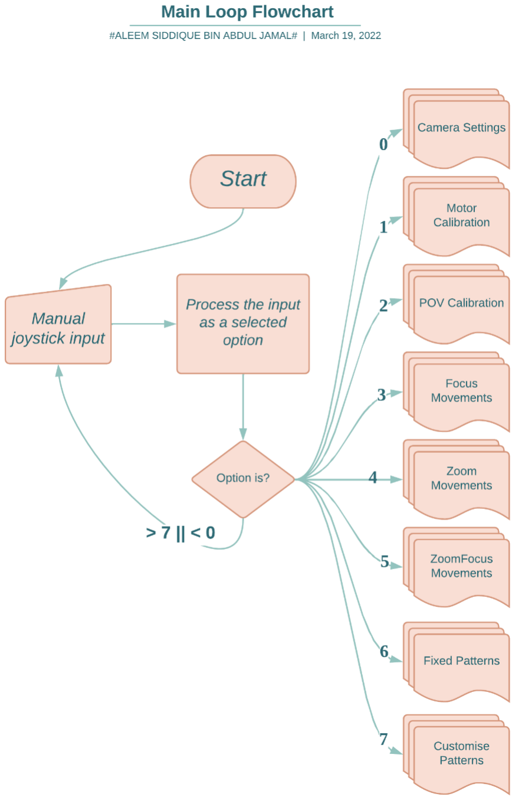
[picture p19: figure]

Figure 29: Flowchart of the main loop

The programming style follows a top-down approach, but I did add some Object-Oriented

principles in the code, which was to ensure that each function in the “separate” file had only

one job to do. Only the interface functions were functions to integrate the distinct functions

from the different files together. A table below to describe the functionalities of each file.

File Name | Task/Role
Motor_ICM.ino (Stepper) Servo_ICM.ino (Servo) | The main Arduino file where all the variables were declared, the pins used, and the setup and loop function.
a_DISPLAY.ino | Functions targeted primarily to the display. The primary functions in this file were the menu and slider function.
b_MOTORCONTROL.ino | Functions involving the stepper driver and stepper motors (for stepper motor setup) or the servo motor themselves. The primary functions in this file were the moving motor and the moving multiple motor function.
c_JOYSTICK.ino | Functions requiring the current user input. Any changes to the joystick movements would update the relevant variables required.
d_INTERFACE.ino | The main integrator. Functions in this file integrated all the three above modules. The functions were customised based on a relevant procedure or movement logic of the motor. If the functions here are insufficient to move a motor in a certain manner, it can easily be added in this file.

Table 8: Functionalities of each file

In a way, the three “module” files function as a library and their files were normally untouched

once done and evaluated. By implementing the code this way, for expendabilities purposes,

only the main Arduino file will need to be touched if other patterns are required. Though, I also

added a way for users to create and customise their own patterns which will be further discussed

in the report.

Some of the global variables are kept in storage to prevent users for redoing some of the

procedures again such as motor calibration or POV calibration.

4.3.1 Display GUI

When a user starts the program, they will be greeted with the main menu screen. The GUI was

coded as intuitive as possible, and instructions were also given for a user to navigate around

the menu. Both prototypes with different motors have the same menu since the overall

functionality remained the same.

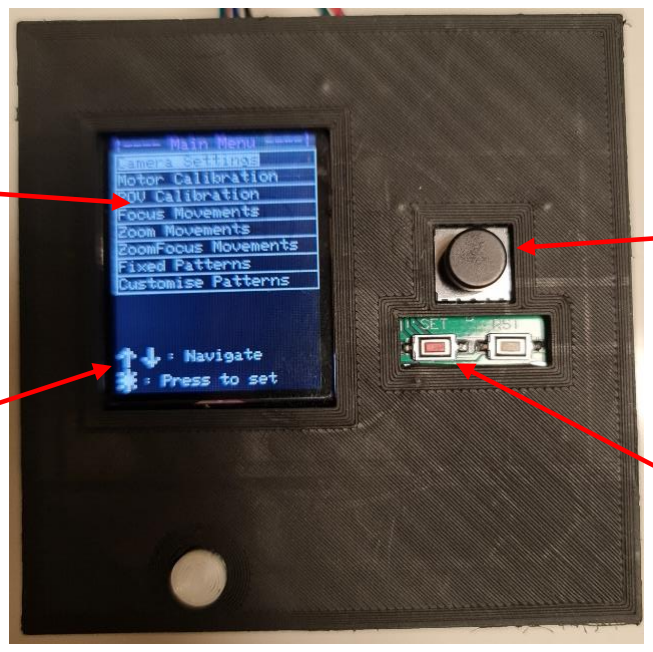
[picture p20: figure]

Figure 30: Main Menu display

There would be a total of eight options in the main menu, of which five of them related to the

motor movements. User would be able to navigate the different options by up & down and

press the select key to select the option chosen. Each option and the functionalities will be

covered. For the implementation of how the UI was done through Arduino, this will be

discussed after explaining the basic GUI that the user will experience.

Navigation keys (Up,
Down, Left, Right)

Select/Set key

Select to current
selected option

Display menu

Navigation
instructions

4.3.1.1 Main Menu GUI

Camera Settings

This was the first option in the main menu. Here, users can swap motor positions. Not all lenses

come with the same Focus and Zoom ring positions. Therefore, a swap motor position here is

necessary for users with different lenses without the need to physically change the hardware

motor wiring.

Figure 31: Camera settings is highlighted and selected

Figure 32: Different settings options

Figure 33: A slider to set the shutter time (the same for motor)

The variables used for the settings was displayed in Figure 32 for users to know the current set

camera settings. In Figure 33, the slider UI was used, and users can set the value by navigating

left and right using the navigation keys. This menu was also the same for the motor movement

time but with a different text.

Camera shutter time refers to the shutter time of the DSLR camera. This does not change the

time of on the camera but must be manually sync to the camera shutter time.

Motor movement time refers to the time needed to execute a sequence. This by default would

always set to -1 to 2 seconds from the shutter time for the DSLR camera to capture the current

scene before the motor movements can happen.

Motor Calibration

Calibration of the motors was needed as the minimum and maximum angle of rotation for the

focus and zoom rings are important during the motor movements.

Figure 34: Motor calibration is selected | Figure 35: Different options in calibration menu

Three options were available to be selected in the calibration menu. Zoom and Focus

calibration and reset all values. Zoom and Focus calibration were straightforward, set the

minimum angle, followed by the maximum angle and this returns the maximum range that the

motor can rotate for the lens. The values here are stored in memory for the Arduino

microcontroller. Users can restart the application/prototype without the need for a recalibration.

However, recalibration will wipe out the values stored, and the new values will be saved

instead.

Figure 36: Calibrate minimum zoom angle | Figure 37: Calibrate maximum zoom angle

Reset the values could be used when changing lens, a quick way to reset the values rather than

recalibrating again.

POV calibration

POV refers to the image that the user wants to capture. A user would want to capture a certain

image by adjusting the zoom and focus of the lens. The calibration is required for the motor to

know the location that it wants to go to or to return after a motor movement sequence is

executed. This ensured that the image was always kept in view at any point of time during the

shoot. The same slider as motor calibration to adjust the appropriate zoom or focus rings.

Figure 38: POV calibration is selected | Figure 39: Adjusting the zoom lens to the desired image

Motor Movements

Focus movements, zoom movements, zoomfocus movements, fixed patterns and customise

patterns all belong to the same hierarchy that was to rotate the motor in a specific way. The

different default patterns can be viewed in Appendix D. For customise patterns however, there

were some differences as it requires users to make their own patterns.

Figure 40: Customise patterns selected

Figure 41: No saved patterns found

Figure 42: Saved pattern available to be executed

Only one pattern could be saved at any point of time and the pattern can have a maximum of

eight sequences. If the pattern is available, user can execute the pattern. Any new pattern

created afterwards will override the previous pattern.

4.3.1.2 Menu UI

The two main UI used for the software is the menu and sliders UI. Regarding the menu UI, it

was split to three parts, a header, a body, and a footer, each were customisable based on the

parameters feed in the function. The code documentation in Figure 43 that was done easily

explained how the menu UI functions.

/**
* ----- MENU ------
* Creates a menu using a string array
* Display which option is being selected *
* [Top of screen] | {Configurable}
* Shutter Speed: __
* Front Motor: ____
* Rear Motor: _____
*
* [Middle of screen]
* |----< Menu Name >----|
* | Option 1
* | Option 2
* | ...
*
* [Bottom of screen]
* < > Move the lens | {Will be dependent on the menu}
* ^v | Select the options
* | o | Select current option
*
* @param array_size | Maximum choices that the menu should have.
* @param string_table[] | Character array of strings to be displayed.
* @param option_selected | Current selected option.
* @param header | Values from -2 to 4, to display varying
headers.
* @param footer | Values from 0 to 2, to display varying footers.
* @param color | uint16_t colors can be used for display.
* @return int | The maximum choices of the menu.
*/
int menu(int array_size, const char *const string_table[],
| | int option_selected, int header=0, int footer=2, uint16_t color=DEEPPINK)

Figure 43: Code snippet of the menu function

Different parameters can be passed to get desired menu on the screen.

string_table[]
is a

character array which requires the title followed by the different option texts: option one, option

two… An example of a menu can be seen in the figure below.

max_option = menu(8, main_menu, option, 0);

An eight-option menu was created with the option selected was highlighted in white. If the

option changes, the menu would update and reflect properly. Users will then know which

option is currently selected visually.

4.3.1.3 Sliders UI

The sliders UI, similarly, to the menu UI also have different customisation available. The slider

function parameters and what each parameter corresponds to can be seen in the code snippet

below.

**
* --- Hotbar Screen ---
* Creates a template for a bar type screen
*
* @param title | Title of the hotbar/screen.
* @param current | Current value.
* @param max_range | Maximum range allowed. (Always start from 0)
* @param current_option | Current option selected. (Only used if `haveBack`
is true)
* @param haveBack | Insert a back button if needed.
* @param header | Values from -2 to 4, to display varying headers.
* @param footer | Values from 0 to 2, to display varying footers.
* @param color | uint16_t colors can be used for display.
* @param updateBar | Only updates certain areas of the hotbar. (Save
Time)
*/
void hotbar(char title[], int current, int max_range,
int current_option=0, bool haveBack=false, int header=0, int footer=3, uint16_t color=WHITE, bool updateBar=false)

Figure 44: Code snippet of hotbar/slider function

The parameter

haveBack=false
referred to an optional back button for user to navigate back

to the previous screen. What parameters correspond to what can be seen in the figure below.

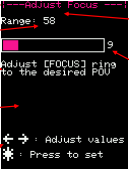
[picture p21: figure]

Figure 45: An example slider screen

The most important parameter for the function is

updateBar
. If the parameter is set to true,

only the current value and the bar of the slider refreshes. As TFT display were slow to refresh,

this was a countermeasure to that.

Title of slider
Header (if needed)
Displays relevant
information if needed

Maximum range
of slider

Current value of the
slider

Footer
Displays navigation
instructions

Slider description

A Back navigation
will be here if needed

4.3.1.4 Motors in Motion UI

Motors in motion UI are a set of screens that will be displayed to the user during a motor

sequence. This was to inform the user of the current task. Paired with a buzzer, the user will be

notified of the start and the end of a motor rotation sequence.

Figure 46: Countdown screen | Figure 47: Moving to the location | Figure 48: Moving back to default

The order of the display is as follow:

5. A countdown screen is displayed before the start of a sequence followed by a beep of

the buzzer.

6. A display of information will be displayed to the user about the current motor status.
7. If the motor must go back to its previous location, the user will be informed by the

display.

8. At the end of the sequence, a beep will be heard, signalling the end of the motor

movements.

4.3.2 Motor Control

Motor control forms the backbone of the software as the controlling of the motors must be done

in these functions. Since the two prototypes using different motors share similar code, the

functions here are different due to the nature of the libraries used.

4.3.2.1 Stepper vs Servo Motors

For the project, I used the “AccelStepper” library to control the drivers and motors for the

stepper motor setup. There were extensive functions available and an easy way for the motors

to remember their current positions. Due to the nature of stepper motors having a lower torque

as compared to servo motors, there was a need to have acceleration to the motor for a smooth

transition. This would prevent the motor from losing additional torque during the rotation

process.

float calcRPM(int steps, float seconds) { return (float)(steps * MS_STEP)/seconds; }

float calcAccel(int steps, float seconds) { float max_speed = calcRPM(steps, seconds); return (float)max_speed / seconds;
}

Figure 49: Code snippet of RPM and acceleration calculations

Also, since there was a timing for the motor to move called ‘motor_time’, the speed calculation

was critical in regulating the time for the motor to complete a fixed rotation. The speed and

acceleration were calculated as shown in Figure 49.

I used the “Servo” library to control the servo motors. Unlike stepper motors, servo motors

remember their current position due to the sensors attached (refer to 4.2 Motors). For stepper

motors, it was based on position coordinates and the library calculates if any negative or

positive movements was required. Furthermore, since the speed for servo motors cannot be

regulated, I had to use delays between each degree angle of rotation.

if (steps_to_move > 0) { // +ve
for (int pos=pos_current; pos<=pos_desired; pos+=1) {
if ((type == 1 && orientation == 0) || (type == 0 && orientation == 1)) { // if rear motor
motor->write(MOTOR_STEPS - (pos + min_pos));
} else {
motor->write(pos + min_pos);
}
delay(toMS((float)shutter_spd/abs(steps_to_move))); }
}
Figure 50: Code snippet of the requirement of a delay

4.3.2.2 Moving singular Motors

Stepper motor

Moving a singular stepper motor was straightforward. From the library, there were only two

functions required to move a motor. Set the position for the stepper motor to move to followed

by the run command in a while loop.

stepper->moveTo(pos_desired * MS_STEP);

//blocking statement
while (stepper->distanceToGo() != 0) { stepper->run();
if(shutter_spd != 0) {
delay(toMS((float)shutter_spd/abs(steps_to_move))); }
}

Figure 51: Code snippet of the moveMotor function

As mentioned earlier, to move the stepper motor to the desired location in a certain time, the

speed of the motor had to change. This was set before the stepper motor was allowed to run.

Servo Motor

Servo motor implementation of moving a motor was less complicated from the library

examples. However, the need to do an extra calculation to decide if the servo motor needed to

go the positive or negative direction made the implementation a little complicated.

int steps_to_move = (pos_desired - pos_current); | Check if the steps to move
| to desired location is
// if +ve, move clockwise | positive or negative
// else -ve, move anti-clockwise
if (shutter_spd != 0) {
if (steps_to_move > 0) { // +ve
for (int pos=pos_current; pos<=pos_desired; pos+=1) { if ((type == 1 && orientation == 0) ||
(type == 0 && orientation == 1)) { // if rear motor motor->write(MOTOR_STEPS - (pos + min_pos));
} else {
motor->write(pos + min_pos);
}
delay(toMS((float)shutter_spd/abs(steps_to_move))); }
}

if (steps_to_move < 0) { // -ve

Figure 52: Code snippet of the direction decider

Selecting the correct motor

In the 4.3.1.1 Main Menu GUI, it mentioned that users can select which motors (the rear or the

front motors) are used for rotating the zoom or focus gears. The implementation on how to

select the correct motor was by using an object pointer and points it to the correct motor that

requires to rotate.

AccelStepper *stepper;
if (type) { | declared | The pointer points to
stepper = orientation ? &front_motor : &rear_motor; | | the correct motor based
} else { | | on set orientation
stepper = orientation ? &rear_motor : &front_motor;
}

An object pointed is

Figure 53: Code snippet of selecting the correct motor to move

4.3.2.3 Moving multiple Motors simultaneously

Moving of multiple motors at the same time was straightforward as it was the same

implementation as singular motors except the need for another run function in the while loop.

while (rear_motor.distanceToGo() != 0 || front_motor.distanceToGo() != 0) {
rear_motor.run(); | Both motors to run. If a motor is done, this function does nothing
} | Delay: Uses average steps to have an ideal delay between the two motors

Condition: waits for both motors to complete their movements

Figure 54: Code snippet on moving multiple motors concurrently

Feeding the right position to go for each motor was simpler as there was not a need for an

object pointer. The values were fed to each individual motor instead depending on the

orientation set.

if (zoom_value == -1) {
rear_position = orientation ? focus_value : zoom_current; front_position = orientation ? zoom_current : focus_value; } else if (focus_value == -1) {
rear_position = orientation ? focus_current : zoom_value; front_position = orientation ? zoom_value : focus_current; } else if (focus_value == -1 && zoom_value == -1) { rear_position = orientation ? focus_current : zoom_current; front_position = orientation ? zoom_current : focus_current;
} else { | The rear and front motors were feed
rear_position = orientation ? focus_value : zoom_value;
front_position = orientation ? zoom_value : focus_value; | with the required movements depending
} | on the orientation of the motors

Figure 55: Code snippet on setting the correct values to the correct motors

4.3.3 Interface Functions

The interface functions combine the functions from separate file, remarkably like the

integration phase of the waterfall model.

4.3.3.1 Calibration

The implementation of calibration for the motors was to get the minimum angle, followed by

the maximum angle and get the range.

zoom range = maximum zoom − minimum zoom

After getting the 3 values required, the minimum angle becomes the absolute minimum

position. For stepper motors, there was a function called setCurrentPos which was able to set

a position relative to the current stepper motor position.

Figure 56: Before setCurrentPos method | Figure 57: After setCurrentPos method

In the example above, the stepper motor sets its current position relative to whatever was

supplied in this case, ‘setCurrentPos(0)’. This suggested that the minimum angle set for the

stepper motor will always be 0.

However, for servo motor, the implementation is slightly different. Since there was not any

method like the ones used in stepper motor, the minimum angle of the servo motor must be

saved. The angle of movements acquired the additional minimum angle during movements.

total angle to move = angle to move + minimum angle

The ‘total angle to move’ was then supplied to the motor to rotate accordingly.

4.3.3.2 Setting a specific distance

There was also a function that allows the user to set a specific distance, this was usually

necessary for custom movements other than the pre-sets available. The backbone of the method

functions similarly to the calibrate function though only 2 values were required, which was the

position to go to. The values can then be supplied to the motor to rotate.

Current
motor angle:
135°

Current
motor angle:
0°

4.3.3.3 Moving motors to a certain distance

The interface function for this integrates the 4.3.1.4 Motors in Motion UI and 4.3.2 Motor

Control. The control of the shutter as well as the buzzer was set here. The sequence to move

the motor to a certain distance are as follow:

1. Users press a certain pattern/sequence to execute.
2. Shutter of the DSLR camera opens and the buzzer starts beeping.
3. The screen starts to display the relevant information to the user while the motor starts

to rotate.

4. Upon the end of the motor movements, shutter of the DSLR camera closes, capturing

the image and the buzzer beeps signalling the end of a sequence.

Controlling the shutter

Shutter control was done simply by using the camera remote shutter release cord connected to

the 2.5mm jack on the board.

Figure 58: A camera remote shutter release cord for Nikon DSLR [22]

Software side, a short pulse of LOW to HIGH was required to toggle the shutter.

void nikonTime() { // Controls the shutter of a Nikon camera digitalWrite(SHUTTER, LOW); // close shutter (fully pressed) delay(20);
digitalWrite(SHUTTER, HIGH);
delay(20);
}
Figure 59: Code snippet of the shutter control function

Buzzer

Controlling the buzzer was done using the inbuilt Arduino library in running any buzzer. The

code can be seen below. Beeps the buzzer for 500ms by default.

void buzz(int delay_ms=500, int freq=1000) {
tone(BUZZER, freq); | // Send freq(Hz) sound signal...
delay(delay_ms); | // ...for delay_ms
noTone(BUZZER); | // Stop sound...
}
Figure 60: Code snipper of the buzzer

4.3.4 Customise Patterns

The implementation of allowing users to create their own patterns was something that I spent

lots of time and was immensely proud of the process.

4.3.2.1 Moving motors from a specified string

The core of the customisation comes from the motor movements. To create custom patterns, I

decided to use strings to store the sequence. Strings can easily be stored in Arduino storage

(more in 4.3.4.2 Setting custom patterns) therefore the string had to be read in a certain format

and execute the instructions embedded in it. Each sequence consisted of 4 aspects with up to 6

characters. An example instruction set can be seen in the table below.

Character position [6] | [0] | [1] | [2] | [3++]
Character option | Z or F | T or F | T or F | Int (0-999)
Representation | Either zoom or focus motor | If the motor needed to go back? | If this is the last sequence in the procedure? | The position of the motor to move to
A full example | ZFF80, FFF40, ZTF18, FTT7

Table 9: An example instruction set of custom patterns

A simple split function was used to separate the string by the comma. Each sequence was then

passed to another function to execute the instruction of the sequence.

void setMotor(char* data, char title[], int custom_itemcount) { bool goBack = false;
if ((data[1] == 'T' || data[1] == 't')) {
goBack = true;
}

bool lastSequence = false;
if ((data[2] == 'T' || data[2] == 't')) { lastSequence = true;
}

if ((data[0] == 'F') || (data[0] == 'f')) {
int steps = strtol(data+3, NULL, 10);
// set focus motor steps to steps
goDist(FOCUS, title, steps, SNOW, goBack, motor_time/custom_itemcount, lastSequence);
}

if ((data[0] == 'Z') || (data[0] == 'z')) {
int steps = strtol(data+3, NULL, 10);
// set zoom motor steps to steps
goDist(ZOOM, title, steps, AZURE, goBack, motor_time/custom_itemcount, lastSequence);
}
}

Checks if the motor has to go back based on the instruction set

Checks if this was
the last sequence

The position to move was passed to the interface function goDist

Figure 61: A code snippet of how the instruction set was read and executed

4.3.4.2 Setting custom patterns

To set a custom pattern, the method is simple for users to use. This was briefly shown in the

Motor Movements section. A flowchart to show the user interaction when creating a new

pattern can be seen below.

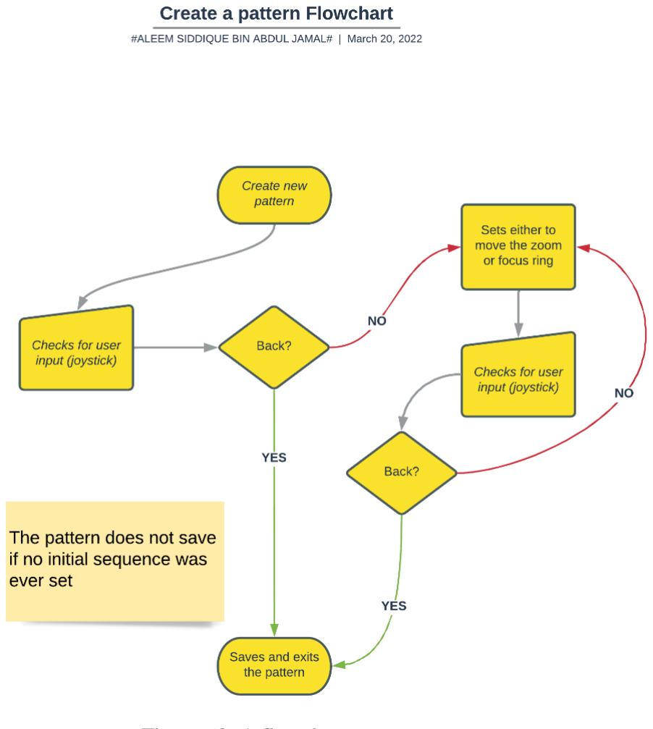
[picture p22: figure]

Figure 62: A flowchart to create a pattern

The pattern will be saved when the user clicks back and executing the pattern/procedure as set

would be possible.

Figure 63: A pattern was successfully saved and can be executed

Creating a new pattern will override the current saved pattern since the microcontroller only

has enough storage to only save 1 array of sequences.

4.4 Integrating with PCB

The project started off on a breadboard before progressing to a PCB board after the hardware

was confirmed. Using EasyEDA online designer tool, I was able to design a PCB and it was

sent to printing. The full PCB board can be viewed in Appendix C.

4.4.1 PCB Designing

The designing process of the PCB started off from the circuit diagram before using the designer

built-in tool to generate a PCB. Thanks to most of the community, most of the hardware used

were available and they were just a drag and paste to the circuit board.

Figure 64: Auto routing tool available on EasyEDA

The PCB wire connection could also be done thanks to the auto routing function of the tool.

However, some tweaks still needed to be done such as thickening the wires and rewire certain

connections.

4.4.2 PCB Assembly

The assembly process of the PCB was done with the help of my professor, Professor Chia. The

hardware required for the PCB was soldered to the PCB and a 3D case was printed to encase

the PCB board along.

Figure 65: A fully assembled PCB board

In the end, the prototype was ready to be extensively evaluated in different kind of conditions

for the long exposure shoot.

Battery was placed
inside the 3D case

Ribbon cables were
used to connect the
display and joystick to
the PCB

An On/Off switch
for easy access

4.4 Integrated Testing

4.4.1 Capturing of objects in motion

For this test, the prototype was setup in a completely pitched black environment other than a

circular RGB light. This RGB light changes as it travels around the loop. The prototype was

evaluated with the help of my FYP mentor, Prof Chia. The type of light used is seen below.

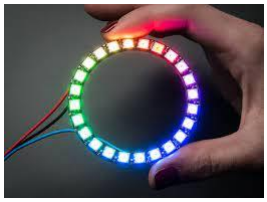
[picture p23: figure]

Figure 66: Circular RGB light used in testing

The 1st sequence used was the zooming to the maximum sequence (see Zoom Movements in

Appendix D). The sequence was to rotate the zoom lens of the DSLR from the current POV to

the maximum range that was set. The result of the photo can be seen below.

Figure 67: The result of using 'zoom to max' [23]

The resulting image was as expected as the lens zoomed in to the RGB light. However, as seen

from the long-exposed image, there are bits of lights with no colours, just white, which suggests

an over exposure.

The next sequence to be used was the ‘zoom to min and focus to max’ pattern (see ZoomFocus

Movements). The sequence rotates both the zoom rings and focus rings at the same time in

opposite direction. The image was to get zoomed out while also get blurry.

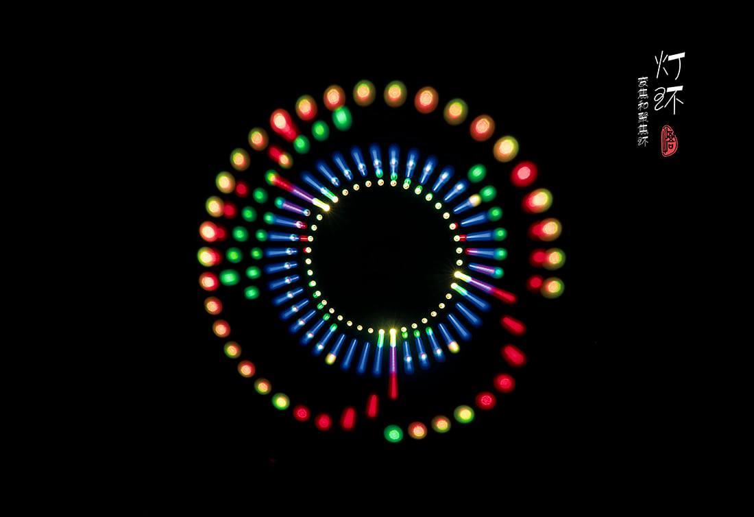
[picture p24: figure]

Figure 68: The result of using 'zoom to min & focus to max' [24]

The resulting long-exposed image looked stunning with the different colours and the blurry

fade out of the image made it a beautiful art piece.

4.4.2 Capturing of static objects

The following testing were done on a building but with colourful lights painting the Old

Singapore Supreme Court Building.

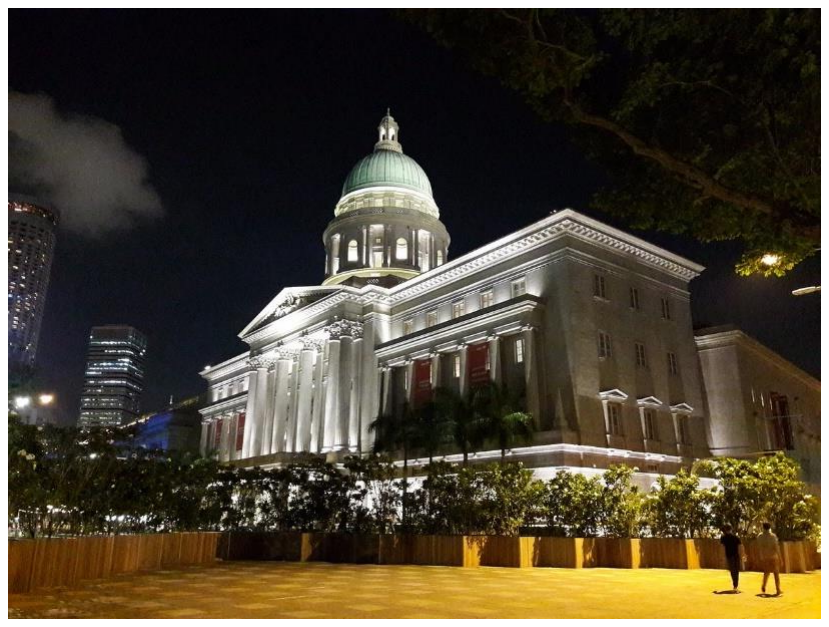
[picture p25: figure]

Figure 69: The Old Supreme Court Building taken without long exposure [25]

The 1

st sequence used for the long exposure shoot was ‘Zoom and Focus to maximum’ (see

ZoomFocus Movements).

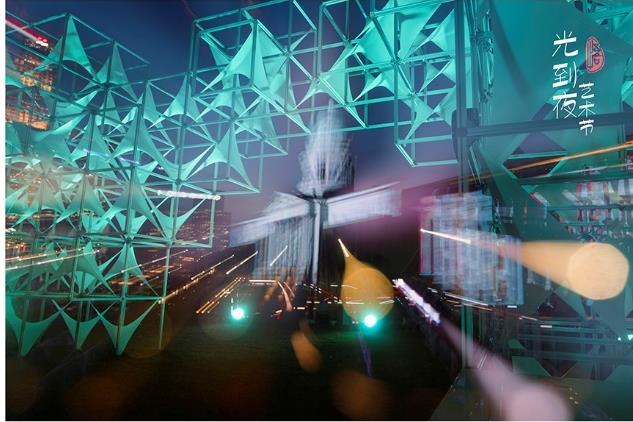
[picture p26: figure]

Figure 70: Old Supreme Building with colourful scaffoldings [26]

The DSLR camera zooms in while also blurring the image resulted in the image above. The

foreground was completely normal, but the background of the Old Supreme Building was

distorted and blurred out.

The next sequence used was the opposite of the sequence used previous, where both the zoom

and focus rings rotates to the minimum. The image gets zoomed out and the foreground gets

blurry.

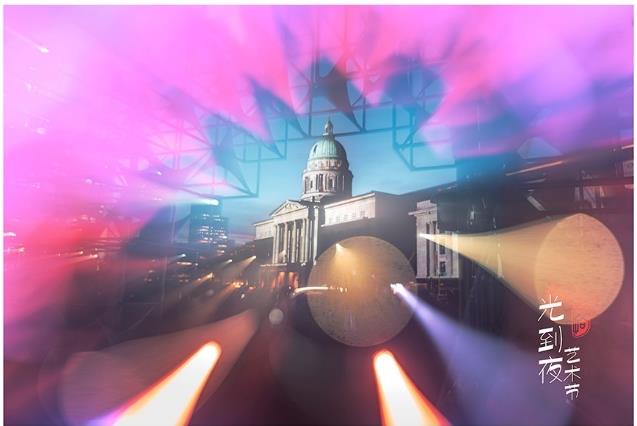
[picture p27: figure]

Figure 71: Old Supreme Court Building painted pink [26]

The images captured of static objects with moving background (in this case, the lights), were

outstanding. Furthermore, all of this were done with a simple push of a button, which was to

select the chosen pattern.

## 5. Challenges and Issues

Even though I was a Computer Engineering student, I had never had any experience with

hardware. Therefore, a lot of hardware was lost due to short circuit or mishandling of the

equipment. However, after reading and learning about the Dos and Don’ts, I was able to avoid

destroying any more hardware.

Also, the lack of knowledge of motors was the main cause to a major setback to the timeline

that I first had in mind. Understanding why the motor could not rotate the DSLR lens. With the

help of online videos to grasp about torque, I was able to change the motor used as well as the

driver resulting in a working motor that could now rotate the lens. It was definitely a huge

success.

The main problem that I had due to the TFT display were the huge amount of program storage

space used in the Arduino Microcontroller. I had many pertaining problems that involves

insufficient storage, and I was required to shorten the code or made it as efficient as possible.

More often than naught, I had to recode the entire portion to make the code function as dynamic

as possible. A total of 3 recode to the entire project had to be done to remove any redundancies

in the code and the approach assisted by following procedural programming.

## 6. Conclusions

To reiterate, this project was designed and implemented to produce a system capable in

conducting a long exposure shoot with unique sequences to get the optimal long-exposure

image results. Through the integration of hardware and software, high precision, and

consistency of the DSLR lens rotation could be achieved. This unfolds an endless possibility

for both experienced and aspiring photographers in long exposure photography.

From the confident results gathered during testing, this project can produce a consistent and

repeatable long exposure image. Paired with the various patterns extended with the custom

pattern that user can input, various beautiful long exposed images can be taken.

Despite the current standings of the project, there are many further optimisations that can be

made. In the PCB, there are connectors for 4 limit switches that can be used to further improve

the calibration of the motors enhancing the system. Furthermore, the project was coded in a

way where future developments can be integrated and added in such as directly controller the

DSLR camera settings itself.

## References

[1] F. Gola, “Long Exposure Photography: A step-by-step guide,” Digital Photography School, [Online]. Available: https://digital-photography-school.com. [Accessed March 2022].
[2] Wirestock, Artist, Traffic with long exposure light trails of cars. [Art]. Freepik.
[3] tawatchai07, Artist, Lotte world amusement park at night and cherry blossom. [Art]. Freepik.
[4] Masterclass, “8 Tips for Shooting Long Exposure Photography,” 8 November 2020. [Online]. Available: https://www.masterclass.com/. [Accessed March 2022].
[5] S. L. Y. &. T. B. Kannappan, “Human consistency evaluation of static video summaries.,” Multimedia Tools and Applications, vol. 78, no. 9, pp. 12281-12306, 2019.
[6] Format Team, “Here’s How To Master The Art Of Long Exposure Photography,” Format Magazine, 21 February 2019. [Online]. Available: https://www.format.com/magazine/resources/photography/long-exposure-photography. [Accessed March 2022].
[7] L. Cole, Artist, Long exposure photography tips. [Art].
[8] Moving Your Lens During Exposure: Photo on the Go with Joe McNally. [Film]. United States of America: Adorama Photography TV, 2014.
[9] B. O. Carroll, “A Comprehensive Beginner’s Guide to Aperture, Shutter Speed, and ISO,” PetaPixel, 25 July 2016. [Online]. Available: https://petapixel.com/aperture-shutter-speed-iso-beginners-guide-photography/. [Accessed March 2022].
[10] S. March, Artist, Seamless Follow Focus Gears. [Art].
[11] J. Waddel, Artist, The Cascading Costs of Waterfall. [Art]. 2019.
[12] S. Lewis, “Waterfall Model,” Tech Target, February 2019. [Online]. Available: https://www.techtarget.com/. [Accessed March 2022].
[13] Arduino, Artist, Arduino Nano. [Art].
[14] Hiwonder, Artist, Hiwonder LD-25MG Strong Torque Digital Servo 25KG Supports Robotic Arm/RC Car/Single Shaft. [Art].
[15] Cambridge, Torque, Cambridge Dictionary, 1995.
[16] E. Hup, Artist, Eng Hup Aluminium Glass Trading. [Art].
[17] ccox, Artist, Customizable Stepper Motor Mount. [Art]. 2017.
[18] D. Sawicz, “Hobby Servo Fundamentals,” 2012.
[19] StepperOnline, Artist, Nema 17 Motors. [Art].

[20] Polulu, “Stepper Motor Drivers,” [Online]. Available: https://www.pololu.com/category/120/stepper-motor-drivers. [Accessed March 2022].
[21] K. McEnaney, Boost Your Photography: Learn Your DSLR, Amazon Kindle, 2013.
[22] Neewer, Artist, Neewer 2.5mm-N1 Off Camera Remote Shutter Release Connecting Cord Cable for Nikon. [Art].
[23] A. C. L. Tien, Artist, Circular Light Zooming to the Max. [Art]. Nanyang Technological University, 2021.
[24] A. C. L. Tien, Artist, The finest lights. [Art]. Nanyang Technological University, 2021.
[25] S. Views, Artist, Photo of City Hall Building. [Art]. 2016.
[26] A. C. L. Tien, Artist, [Art]. Nanyang Technological University, 2022.

## Appendix A

Circuit Diagram of Project (Stepper Motors)

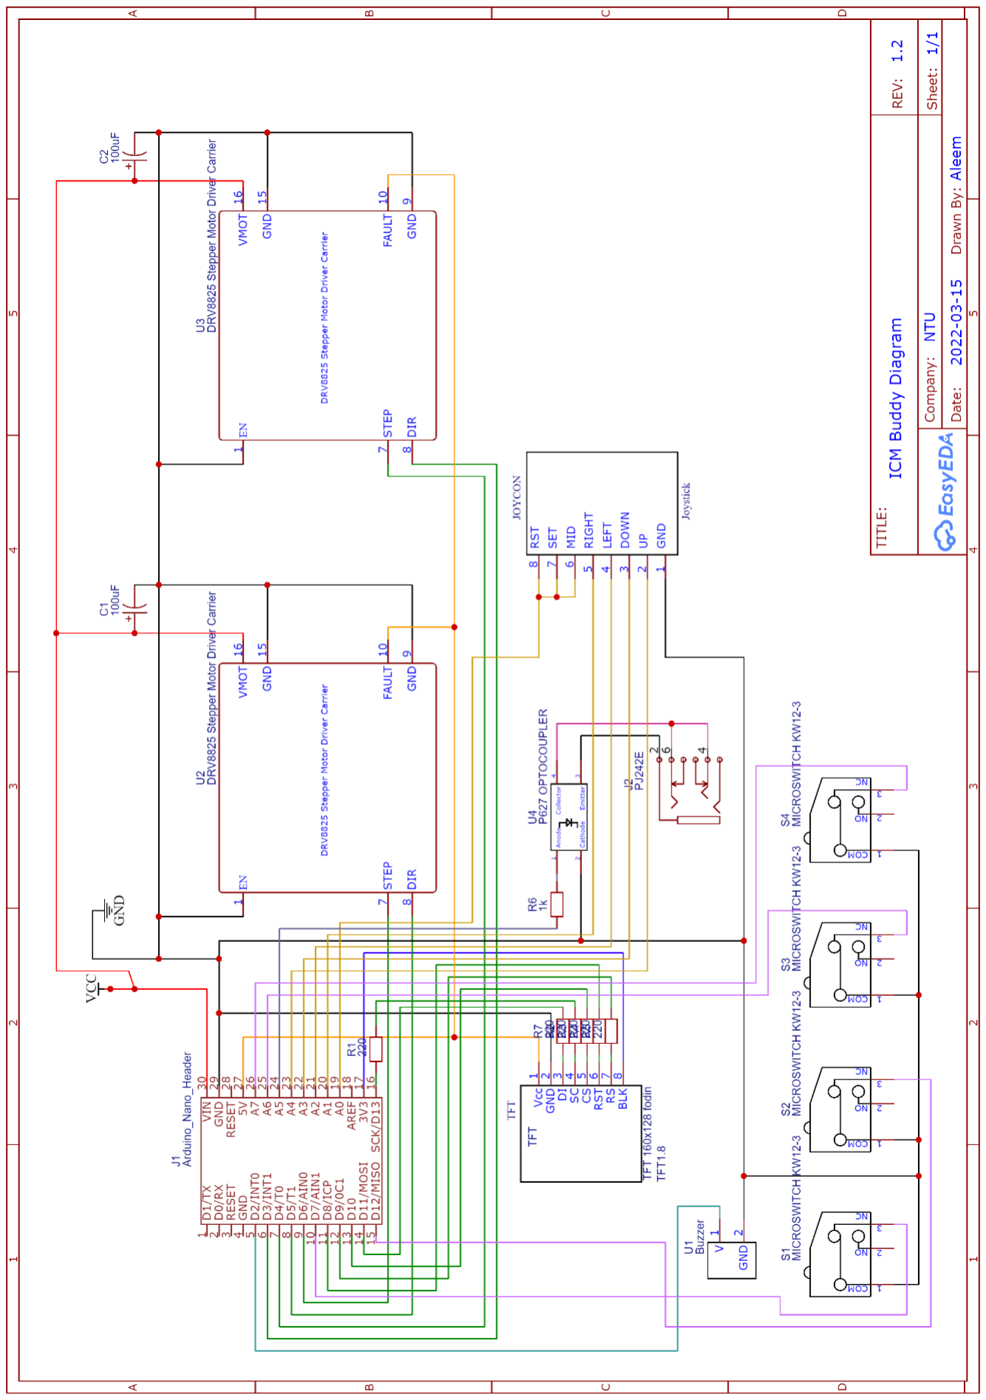
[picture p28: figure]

Figure 72: Circuit Diagram of Project (Stepper Motors)

## Appendix B

Circuit Diagram of Project (Servo Motors)

Figure 73: Circuit Diagram of project (Servo Motors)

## Appendix C

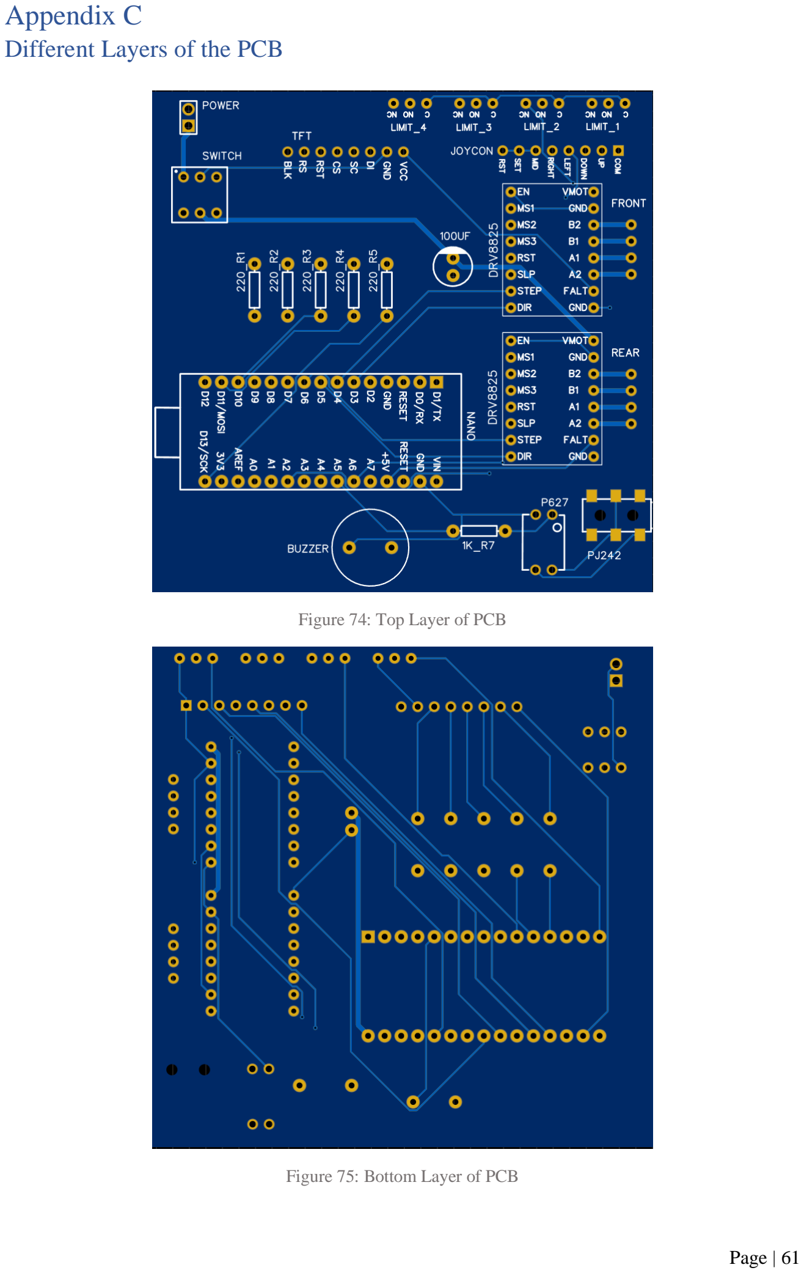
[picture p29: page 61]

Different Layers of the PCB

Figure 74: Top Layer of PCB

Figure 75: Bottom Layer of PCB

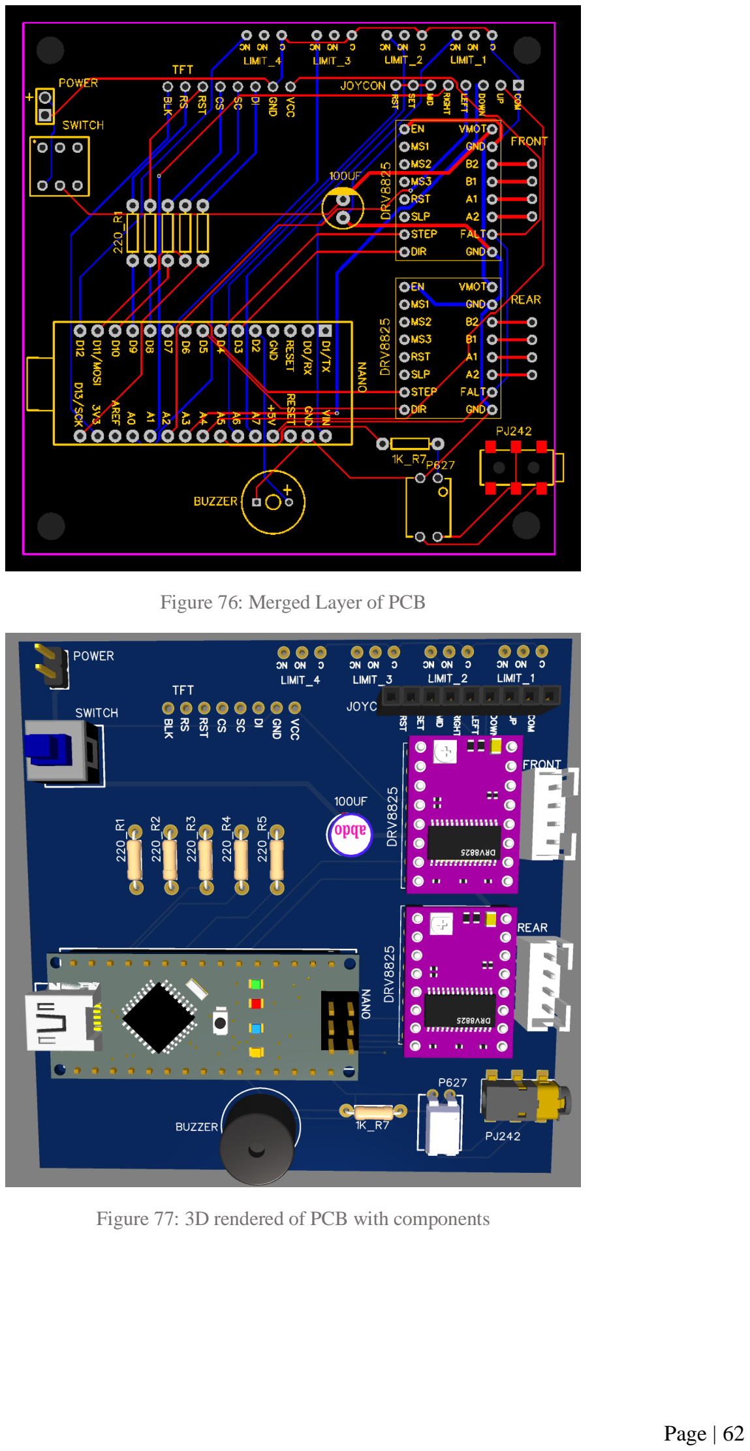
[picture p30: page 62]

Figure 76: Merged Layer of PCB

Figure 77: 3D rendered of PCB with components

## Appendix D

Available Pre-sets

Focus Movements

Figure 78: Focus Movements is selected | Figure 79: The different patterns available

Zoom Movements

Figure 80: Zoom Movements is selected | Figure 81: The different patterns available

ZoomFocus Movements

Figure 82: ZoomFocus Movements is selected | Figure 83: The different patterns available

Fixed Patterns

Figure 84: Fixed Patterns is selected | Figure 85: The different patterns available

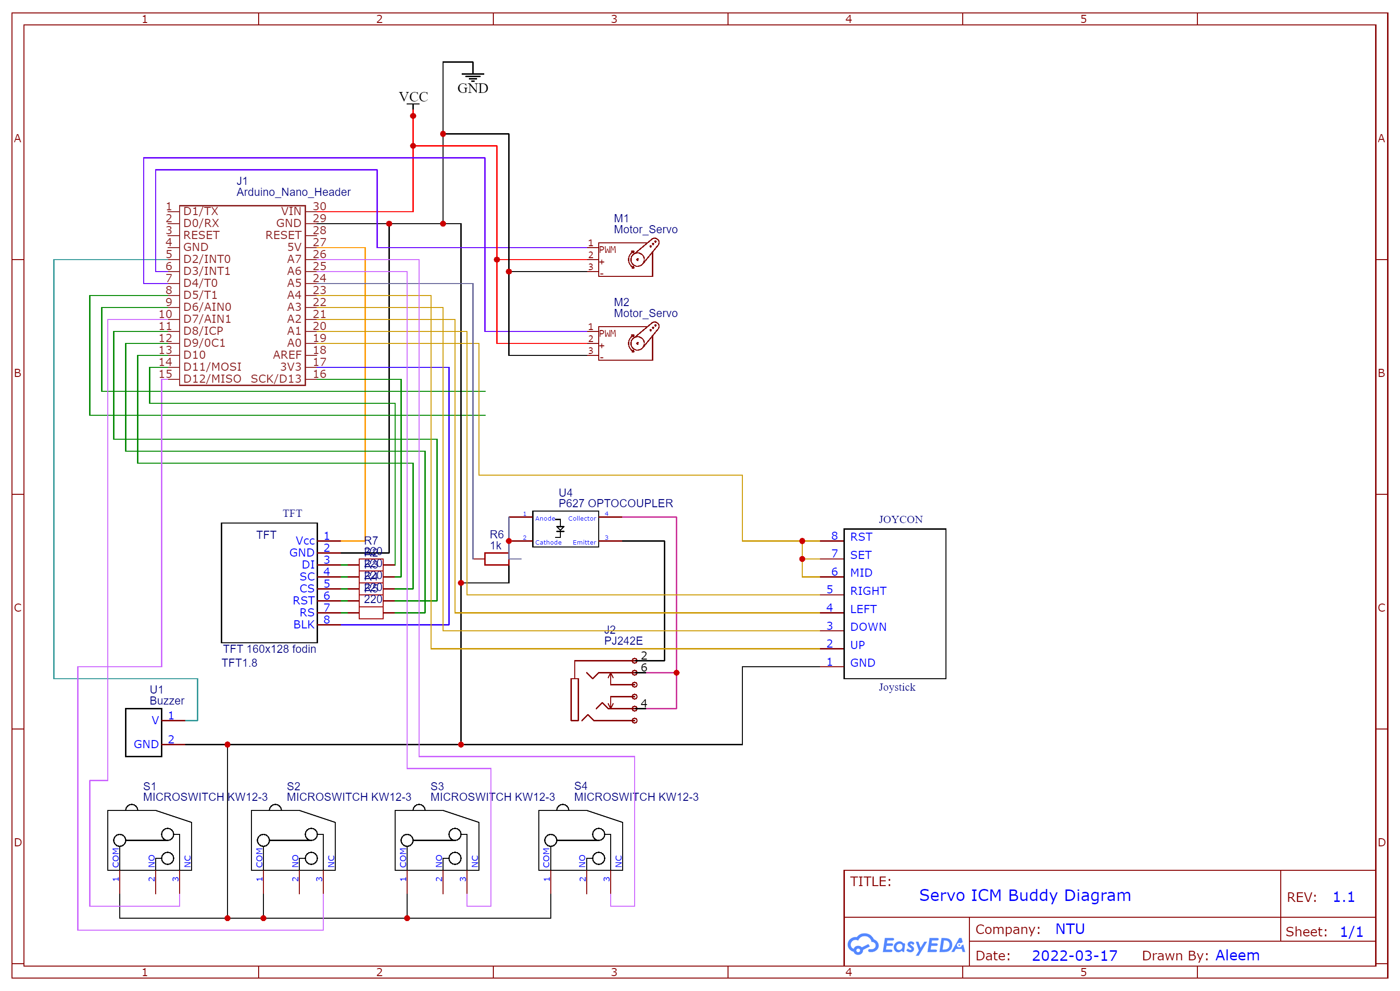
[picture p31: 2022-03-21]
.images/Schematic_FYP Motor ICM_2022-03-17.png

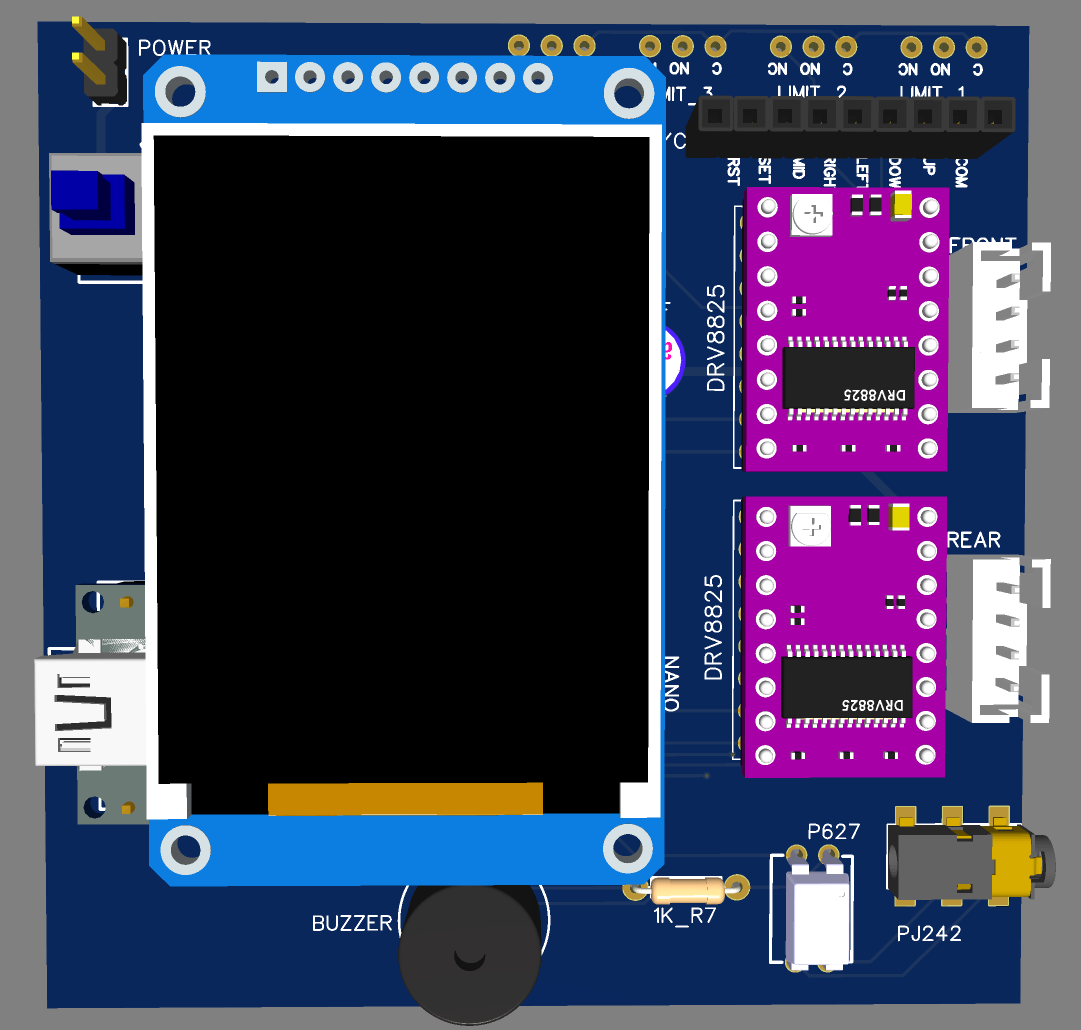
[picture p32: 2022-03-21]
.images/3D_PCB_1.png

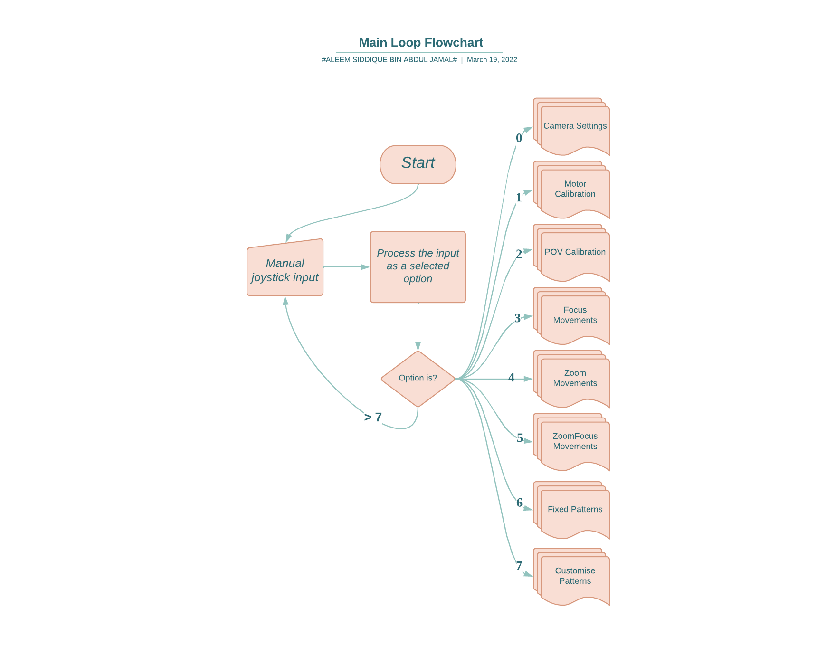
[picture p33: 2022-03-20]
.images/Main Loop Flowchart.png

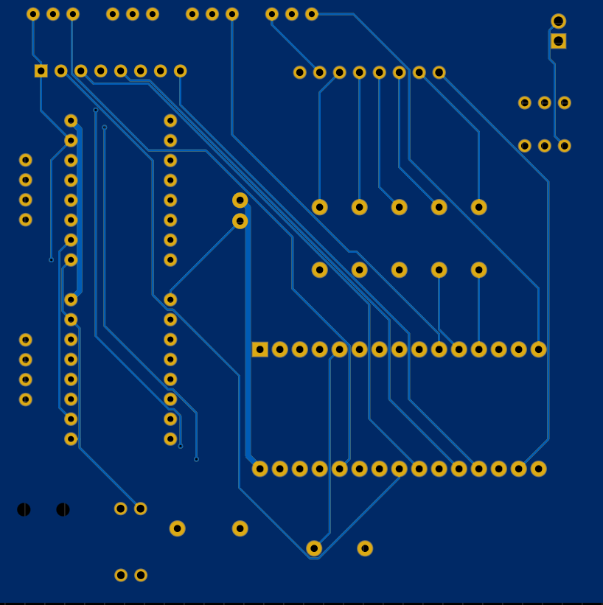
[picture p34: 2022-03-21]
.images/bottom_layer_PCB.png

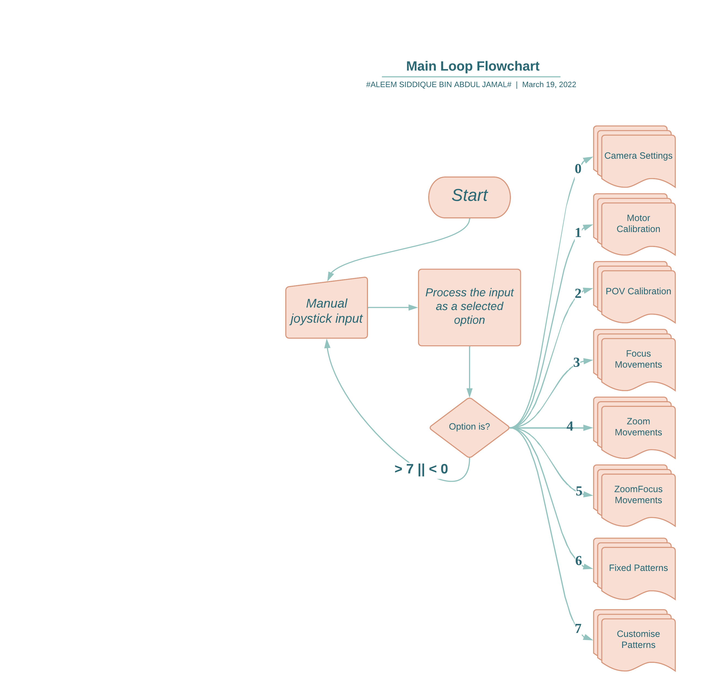
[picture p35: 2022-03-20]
.images/Main Loop Flowchart (2).png

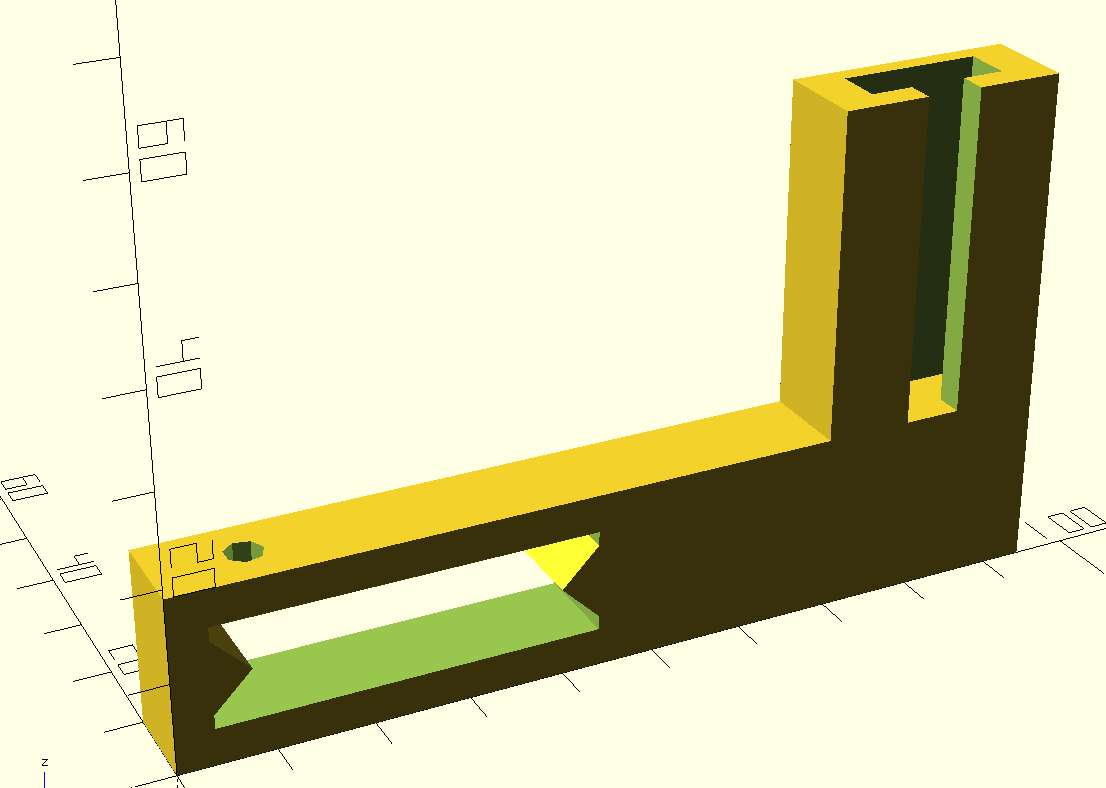
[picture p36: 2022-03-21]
.images/modified_base.PNG

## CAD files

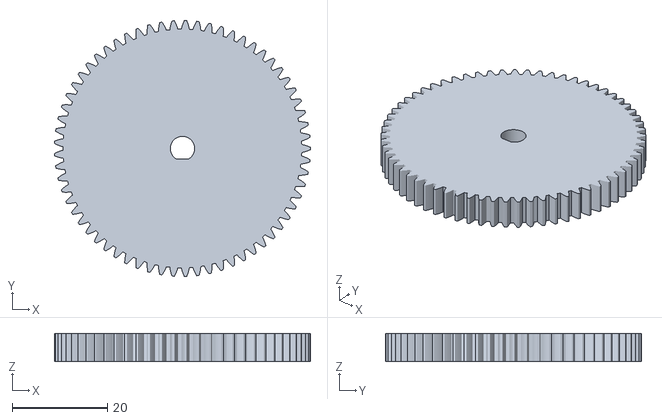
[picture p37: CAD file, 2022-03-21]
.3D_Designs/.stl files/gears_65t_5d.stl
53.7 x 53.8 x 5.88

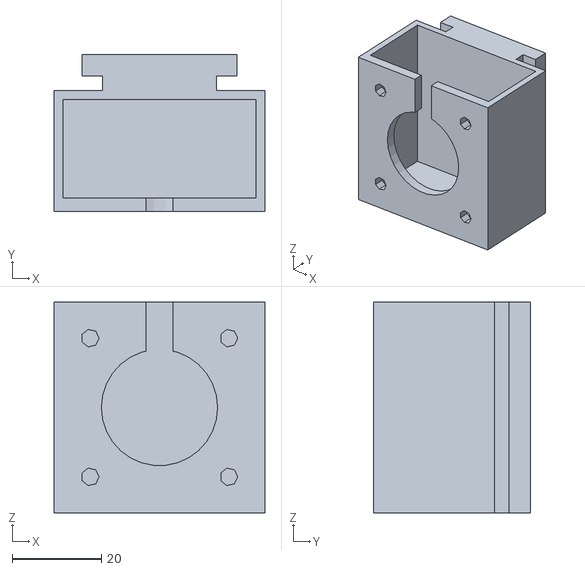
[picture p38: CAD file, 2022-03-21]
.3D_Designs/.stl files/nema17_mount_biggerTslot.stl
47.2 x 35.0 x 47.2

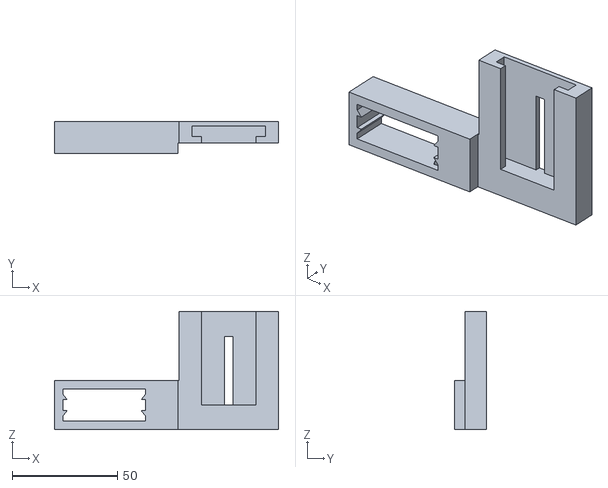
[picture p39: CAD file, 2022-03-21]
.3D_Designs/.stl files/base_mount_biggerTslot_Rear.stl
106.4 x 15.0 x 56.2

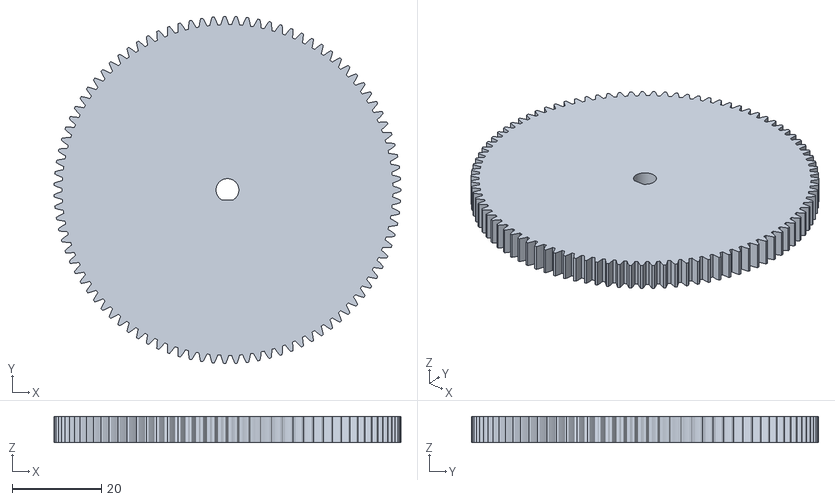
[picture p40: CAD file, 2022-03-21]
.3D_Designs/.stl files/gear_mod08_5mm_77mm.stl
77.7 x 77.8 x 5.88

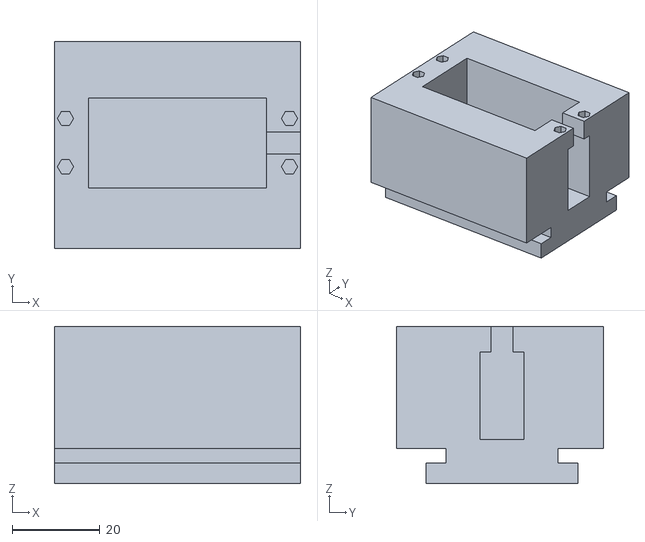
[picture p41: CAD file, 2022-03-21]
.3D_Designs/.stl files/servo_mount_biggerTslot_v2.stl
56.0 x 47.2 x 35.8

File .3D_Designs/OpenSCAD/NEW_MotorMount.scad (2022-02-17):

//CUSTOMIZER VARIABLES

/* [Basic_Parameters] */

// Stepper Motor Size
motor_index = 4;	// [0:NEMA 8, 1:NEMA 11, 2:NEMA 14, 3:NEMA 16, 4:NEMA 17, 5:NEMA 23, 6:NEMA 34, 7:NEMA 42]

// Parallel or Perpendicular (will need supports)
orientation = 0;	// [0:Parallel, 1:Perpendicular]

// mount thickness, in mm
thickness = 2.0;    // [2:0.1:10]

// Openbeam size, in mm
openbeam_size = 10;   // [10:50]

// Openbeam bolt diameter, in mm
beam_bolt_diameter = 3.0;    // [2:0.1:40]

// Openbeam slot diameter for tight fit, in mm
slot_diameter = 3.1;    // [2:0.1:40]

// Openbeam slot distance to edge for tight fit, in mm
slot_depth = 4.5;    // [2:0.1:40]

//CUSTOMIZER VARIABLES END



// use motor size choice to set the important values

// Values are from multiple sources - nobody seems to have all the numbers right in one place!
// And even different manufacturers can't quite agree on all the dimensions!
// I'm open to corrections and additions - but there had better be a good source behind the new values.

// [ motor width in mm (calculated from inches/10), bolt size in mm, bolt spacing in mm, center hole diameter in mm, name ]
motor_templates = [
    [ 0.8*25.4,   2,    16,   15, "NEMA 8"  ],
    [ 1.1*25.4, 2.5,    23,   22, "NEMA 11" ],
    [ 1.4*25.4,   3,    26,   22, "NEMA 14" ],
    [ 1.6*25.4,   3,    31,   22, "NEMA 16" ],
    [ 1.7*25.4,   3,    31,   22, "NEMA 17" ],
    [ 2.3*25.4, 5.0,  47.1, 38.1, "NEMA 23" ],
    [ 3.4*25.4, 6.5,  69.6,   73, "NEMA 34" ],
    [ 4.2*25.4, 8.5,  89.0, 55.5, "NEMA 42" ],
];

motor_width = motor_templates[motor_index][0];
bolt_diameter = motor_templates[motor_index][1];
bolt_radius = (bolt_diameter+1) / 2;
bolt_spacing = motor_templates[motor_index][2];
bolt_inset = (motor_width - bolt_spacing) / 2;
center_diameter = motor_templates[motor_index][3];
center_radius = (center_diameter+4) / 2; // 3 mm margin wasn't quite enough on some motors

temp_length = max( motor_width, 5*beam_bolt_diameter );
temp_width = max( motor_width, openbeam_size+thickness*2 );
temp_length2 = max( motor_width, openbeam_size+thickness*2 );
temp_width2 = max( motor_width, 5*beam_bolt_diameter );
mount_width = (orientation == 1) ? temp_width2 : temp_width;
mount_length = (orientation == 1) ? temp_length2 : temp_length  + 25;
mount_offset_x = (mount_width - motor_width) / 2;
mount_offset_z = (mount_length - motor_width) / 2;
beam_bolt_radius = (beam_bolt_diameter+1) / 2;


// Sanity checks
if( motor_width <= 0 || bolt_diameter <= 0
    || openbeam_size <= 0 || beam_bolt_diameter <= 0
    || slot_diameter <= 0 || slot_depth <= 0)
{
    echo("<B>Error: Missing important parameters, possibly wrong motor index</B>");
}

// Sanity checks
if( openbeam_size <= 2*beam_bolt_diameter ||
    openbeam_size <= 2*slot_diameter ||
    openbeam_size <= 2*slot_depth)
{
    echo("<B>Error: Parameters result in bad beam attachment</B>");
}

//use <T_Slot.scad>
//use <T-slot_nut.scad>


// Vertical mounting
//rotate([-90,0,90])
    //TSlotNut(5);

//translate([-3,0,19])
    //2020Profile(30);
// our object, flat on xy plane for easy STL generation

//rotate([0,0,90])
//prism(10, 5, 5);

//translate([-5,0,5])
//rotate([90,0,90])
//prism(10, 5, 5);


// motor mount

/*
mirror([0,1,0])
translate([2,0,2])
rotate([90,0,0])
motor_mount();
*/


//motor_mount();
// tslot beam
//tslot_beam();

//t_slot_beam(35,10);

mirror([0,1,0])
base(15, 35+9.5);

//translate([10,-3,34])
//rotate([90,0,0])
    //TSlotNut(5);


//translate([(mount_width-mount_offset_x)/2/2/2/2/2/2/2/2,-3,temp_length+2])
//rotate([-90,0,0])
    //beam_mount();

// beam base
//beam_base();

//translate([mount_width/2-mount_offset_x,25,37])
//rotate([90,0,0])
//linear_extrude(height=30)
    //import("openbeam.dxf");

module prism(l, w, h){
   polyhedron(
           points=[[0,0,0], [l,0,0], [l,w,0], [0,w,0], [0,w,h], [l,w,h]],
           faces=[[0,1,2,3],[5,4,3,2],[0,4,5,1],[0,3,4],[5,2,1]]
           );
   }


module base(t_thickness, slot_height=35) {
    
    thickness = 4;
    m_width = 39+0.2;
    m_height = 15+0.3;  // 10 for DMP140
    //m_height = 10+1;
    padded_width = m_width + thickness*2;
    padded_height = m_height + thickness*2;
    
    // prism length
    p_length = 2.5;  // 4.2 for DMP140
    //p_length = 4.0;
    p_width = 2.0;
    //p_width = 4.0;
    
    
    difference () {
        
        // stuff to build up
        union() { 
            
            // original cube
            cube([padded_width, t_thickness, padded_height]);
            
            
        }
        
        // things to cut out
        
        translate([padded_width/2-((m_width)/2), 0,padded_height/2-(m_height/2)])
        cube([m_width, t_thickness, m_height]);
        
        // screw
        translate([m_width-(3.8/2)+1.9+0.8,t_thickness/2-3,0])
        cylinder(thickness, d=3.8);
        
    }
    
    //gap = 1.5;
    gap = 2.5;
    
    union () {
        
      // triangles supports
      
      translate([thickness+m_width,t_thickness,thickness+gap])
        rotate([90,0,-90])
        prism(t_thickness, p_length, p_width);  
      
      translate([thickness+m_width,0,padded_height-thickness-gap])  
      rotate([-90,0,90])
        prism(t_thickness, p_length, p_width);
      
      translate([thickness,0,thickness+gap])  
      rotate([90,0,90])
       prism(t_thickness,p_length, p_width); 
        
      translate([thickness,t_thickness,padded_height-thickness-gap])  
      rotate([-90,0,-90])
        prism(t_thickness, p_length, p_width);
        
        
      // extended beam
      slot_thickness = 2;
      t_padded_width = motor_width + slot_thickness*2;
      extra_length = 22+10-20;
      t_slot_thickness = 10;
      
      translate([padded_width,0,0])
      cube([extra_length-0.5, t_thickness, padded_height]);
      
      translate([padded_width+extra_length-1,t_thickness-t_slot_thickness,0])
      cube([1, t_slot_thickness, padded_height]);
      
      translate([padded_width+extra_length,t_thickness-t_slot_thickness,0])
      cube([t_padded_width, t_slot_thickness, padded_height/2]);
      
      
      translate([extra_length+padded_width,t_thickness-t_slot_thickness,padded_height/2])
      t_slot_beam(slot_height, t_slot_thickness);
        
    }
    
   
}


module t_slot_beam(t_length, t_thickness) {
    slot_length = t_length;
    slot_thickness = t_thickness;
    padded_width = mount_width+thickness*2;
    
    difference() {
        
        // stuff to build up
        union() {
            
            
            cube([padded_width, slot_thickness, slot_length]);
        }
        
        //things to cut out
        t_slot_length = 3;
         t_slot_width = 15+20;
         t_slot_thickness = 6+20;
        
        translate([padded_width/2-(t_slot_thickness/2),0, 0])
        cube([t_slot_thickness, t_slot_length, slot_length]);
        
        translate([padded_width/2-(t_slot_width/2),t_slot_length, 0])
        cube([t_slot_width, thickness+3, slot_length]);
        
        translate([padded_width/2-(4/2),t_slot_length+thickness+3, slot_length/2-padded_width/2])
        cube([4,2,slot_length-10.5]);
    }
    

}
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

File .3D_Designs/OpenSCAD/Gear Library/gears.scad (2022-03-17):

/* [Basic Gear Parameters] */
Module = 1; // 0.01

Gear_type = "spur_gear"; // ["rack":Rack, "spur_gear":Spur gear, "herringbone_gear":Herringbone gear, "rack_and_pinion": Rack and pinion, "annular_spur_gear":Annular/Internal spur gear, "annular_herringbone_gear":Annular/Internal herrinbone gear, "planetary_gear":Planetary gear, "bevel_gear":Bevel gear, "bevel_gears":Bevel gears, "herringbone_bevel_gear":Herringbone bevel gear, "herringbone_bevel_gears":Herringbone bevel gears, "worm":Worm, "worm_drive":Worm drive]

width = 5.0; // 0.01
teeth = 30;
bore = 3.9; // 0.01
straight = false;

/* [Advanced Parameters] */
hub = true;
hub_diameter = 6; // 0.01
hub_thickness = 5; // 0.01
// (Weight optimization if applicable)
optimized = false;
pressure_angle = 20; // 0.01
helix_angle = 20; // 0.01
clearance = 0.05; // 0.01

/* [Multi-gear configurations] */
idler_teeth = 36;
idler_bore = 3; // 0.01
assembled = true;

/* [Rack parameters] */
rack_length = 50; // 0.01
rack_height = 4; // 0.01

/* [Worm parameters] */
// Worm lead angle                                                                (For final worm diameter, see also number of starts.)
lead_angle = 4; // 0.01
// Number of starts                                                                (For final worm diameter, see also lead angle.)
worm_starts = 1;
// Worm bore                                             (Please note: The bore in Basic Gear Parameters is used for the bore of the worm gear, not the worm.)
worm_bore = 3; // 0.01
worm_length = 6; // 0.01

/* [Bevel gear parameters] */
bevel_angle = 45; // 0.01
bevel_width = 5; // 0.01
shaft_angle = 90; // 0.01

/* [Annular/internal gear parameters] */
rim_width = 3; // 0.01

/* [Planetary gear parameters] */
solar_teeth = 20;
planet_teeth = 10;
number_of_planets = 3;


module customizer_separator() {}

finalHelixAngle = straight ? 0 : helix_angle;
final_hub_diameter = hub ? hub_diameter : 0;
final_hub_thickness = hub ? hub_thickness : 0;

$fn = 96;

/* Bibliothek für Evolventen-Zahnräder, Schnecken und Zahnstangen

Enthält die Module
- zahnstange(modul, laenge, hoehe, breite, eingriffswinkel=20, schraegungswinkel=0)
- stirnrad(modul, zahnzahl, breite, bohrung, eingriffswinkel=20, schraegungswinkel=0, optimiert=true)
- pfeilrad(modul, zahnzahl, breite, bohrung, eingriffswinkel=20, schraegungswinkel=0, optimiert=true)
- zahnstange_und_rad (modul, laenge_stange, zahnzahl_rad, hoehe_stange, bohrung_rad, breite, eingriffswinkel=20, schraegungswinkel=0, zusammen_gebaut=true, optimiert=true)
- hohlrad(modul, zahnzahl, breite, randbreite, eingriffswinkel=20, schraegungswinkel=0)
- pfeilhohlrad(modul, zahnzahl, breite, randbreite, eingriffswinkel=20, schraegungswinkel=0)
- planetengetriebe(modul, zahnzahl_sonne, zahnzahl_planet, anzahl_planeten, breite, randbreite, bohrung, eingriffswinkel=20, schraegungswinkel=0, zusammen_gebaut=true, optimiert=true)
- kegelrad(modul, zahnzahl,  teilkegelwinkel, zahnbreite, bohrung, eingriffswinkel=20, schraegungswinkel=0)
- pfeilkegelrad(modul, zahnzahl, teilkegelwinkel, zahnbreite, bohrung, eingriffswinkel=20, schraegungswinkel=0)
- kegelradpaar(modul, zahnzahl_rad, zahnzahl_ritzel, achsenwinkel=90, zahnbreite, bohrung, eingriffswinkel = 20, schraegungswinkel=0, zusammen_gebaut=true)
- pfeilkegelradpaar(modul, zahnzahl_rad, zahnzsahl_ritzel, achsenwinkel=90, zahnbreite, bohrung, eingriffswinkel = 20, schraegungswinkel=0, zusammen_gebaut=true)
- schnecke(modul, gangzahl, laenge, bohrung, eingriffswinkel=20, steigungswinkel=10, zusammen_gebaut=true)
- schneckenradsatz(modul, zahnzahl, gangzahl, breite, laenge, bohrung_schnecke, bohrung_rad, eingriffswinkel=20, steigungswinkel=0, optimiert=true, zusammen_gebaut=true)

Beispiele für jedes Modul befinden sich auskommentiert am Ende dieser Datei

Autor:		Dr Jörg Janssen
Stand:		29. Oktober 2018
Version:	2.3
Lizenz:		Creative Commons - Attribution, Non Commercial, Share Alike

Erlaubte Module nach DIN 780:
0.05 0.06 0.08 0.10 0.12 0.16
0.20 0.25 0.3  0.4  0.5  0.6
0.7  0.8  0.9  1    1.25 1.5
2    2.5  3    4    5    6
8    10   12   16   20   25
32   40   50   60

*/


// Allgemeine Variablen
pi = 3.14159;
rad = 57.29578;
spiel = clearance;	// Spiel zwischen Zähnen

/*	Wandelt Radian in Grad um */
function grad(eingriffswinkel) = eingriffswinkel*rad;

/*	Wandelt Grad in Radian um */
function radian(eingriffswinkel) = eingriffswinkel/rad;

/*	Wandelt 2D-Polarkoordinaten in kartesische um
    Format: radius, phi; phi = Winkel zur x-Achse auf xy-Ebene */
function pol_zu_kart(polvect) = [
	polvect[0]*cos(polvect[1]),  
	polvect[0]*sin(polvect[1])
];

/*	Kreisevolventen-Funktion:
    Gibt die Polarkoordinaten einer Kreisevolvente aus
    r = Radius des Grundkreises
    rho = Abrollwinkel in Grad */
function ev(r,rho) = [
	r/cos(rho),
	grad(tan(rho)-radian(rho))
];

/*  Kugelevolventen-Funktion
    Gibt den Azimutwinkel einer Kugelevolvente aus
    theta0 = Polarwinkel des Kegels, an dessen Schnittkante zur Großkugel die Evolvente abrollt
    theta = Polarwinkel, für den der Azimutwinkel der Evolvente berechnet werden soll */
function kugelev(theta0,theta) = 1/sin(theta0)*acos(cos(theta)/cos(theta0))-acos(tan(theta0)/tan(theta));

/*  Wandelt Kugelkoordinaten in kartesische um
    Format: radius, theta, phi; theta = Winkel zu z-Achse, phi = Winkel zur x-Achse auf xy-Ebene */
function kugel_zu_kart(vect) = [
	vect[0]*sin(vect[1])*cos(vect[2]),  
	vect[0]*sin(vect[1])*sin(vect[2]),
	vect[0]*cos(vect[1])
];

/*	prüft, ob eine Zahl gerade ist
	= 1, wenn ja
	= 0, wenn die Zahl nicht gerade ist */
function istgerade(zahl) =
	(zahl == floor(zahl/2)*2) ? 1 : 0;

/*	größter gemeinsamer Teiler
	nach Euklidischem Algorithmus.
	Sortierung: a muss größer als b sein */
function ggt(a,b) = 
	a%b == 0 ? b : ggt(b,a%b);

/*	Polarfunktion mit polarwinkel und zwei variablen */
function spirale(a, r0, phi) =
	a*phi + r0; 

/*	Kopiert und dreht einen Körper */
module kopiere(vect, zahl, abstand, winkel){
	for(i = [0:zahl-1]){
		translate(v=vect*abstand*i)
			rotate(a=i*winkel, v = [0,0,1])
				children(0);
	}
}

/*  Zahnstange
    modul = Höhe des Zahnkopfes über der Wälzgeraden
    laenge = Länge der Zahnstange
    hoehe = Höhe der Zahnstange bis zur Wälzgeraden
    breite = Breite eines Zahns
    eingriffswinkel = Eingriffswinkel, Standardwert = 20° gemäß DIN 867. Sollte nicht größer als 45° sein.
    schraegungswinkel = Schrägungswinkel zur Zahnstangen-Querachse; 0° = Geradverzahnung */
module zahnstange(modul, laenge, hoehe, breite, eingriffswinkel = 20, schraegungswinkel = 0) {

	// Dimensions-Berechnungen
	modul=modul*(1-spiel);
	c = modul / 6;												// Kopfspiel
	mx = modul/cos(schraegungswinkel);							// Durch Schrägungswinkel verzerrtes modul in x-Richtung
	a = 2*mx*tan(eingriffswinkel)+c*tan(eingriffswinkel);		// Flankenbreite
	b = pi*mx/2-2*mx*tan(eingriffswinkel);						// Kopfbreite
	x = breite*tan(schraegungswinkel);							// Verschiebung der Oberseite in x-Richtung durch Schrägungswinkel
	nz = ceil((laenge+abs(2*x))/(pi*mx));						// Anzahl der Zähne
	
	translate([-pi*mx*(nz-1)/2-a-b/2,-modul,0]){
		intersection(){											// Erzeugt ein Prisma, das in eine Quadergeometrie eingepasst wird
			kopiere([1,0,0], nz, pi*mx, 0){
				polyhedron(
					points=[[0,-c,0], [a,2*modul,0], [a+b,2*modul,0], [2*a+b,-c,0], [pi*mx,-c,0], [pi*mx,modul-hoehe,0], [0,modul-hoehe,0],	// Unterseite
						[0+x,-c,breite], [a+x,2*modul,breite], [a+b+x,2*modul,breite], [2*a+b+x,-c,breite], [pi*mx+x,-c,breite], [pi*mx+x,modul-hoehe,breite], [0+x,modul-hoehe,breite]],	// Oberseite
					faces=[[6,5,4,3,2,1,0],						// Unterseite
						[1,8,7,0],
						[9,8,1,2],
						[10,9,2,3],
						[11,10,3,4],
						[12,11,4,5],
						[13,12,5,6],
						[7,13,6,0],
						[7,8,9,10,11,12,13],					// Oberseite
					]
				);
			};
			translate([abs(x),-hoehe+modul-0.5,-0.5]){
				cube([laenge,hoehe+modul+1,breite+1]);			// Quader, der das Volumen der Zahnstange umfasst
			}	
		};
	};	
}

/*  Stirnrad
    modul = Höhe des Zahnkopfes über dem Teilkreis
    zahnzahl = Anzahl der Radzähne
    breite = Zahnbreite
    bohrung = Durchmesser der Mittelbohrung
    eingriffswinkel = Eingriffswinkel, Standardwert = 20° gemäß DIN 867. Sollte nicht größer als 45° sein.
    schraegungswinkel = Schrägungswinkel zur Rotationsachse; 0° = Geradverzahnung
	optimiert = Löcher zur Material-/Gewichtsersparnis bzw. Oberflächenvergößerung erzeugen, wenn Geometrie erlaubt */
module stirnrad(modul, zahnzahl, breite, bohrung, nabendicke=0, nabendurchmesser=0, eingriffswinkel = 20, schraegungswinkel = 0, optimiert = true) {
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

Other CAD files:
.3D_Designs/.stl files/base_mount_biggerTslot_Front.stl
.3D_Designs/OpenSCAD/OpenBeamMotorMount.scad
.3D_Designs/OpenSCAD/servo_mount.scad

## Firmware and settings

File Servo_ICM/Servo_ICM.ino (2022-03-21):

/*
 * ICM BUDDY for DSLR Cameras
 * 
 * Hardwares used in this project:
 * - 2 Servo Motors
 * - 1 TFT 1.8 Screen (Requires 5 220 ohm resistors)
 * - 1 Joystick
 * 
 * Additional Hardwares:
 * - Buzzer
 * - Shutter/Flash Remote Camera Switch
 * - Limit Switches
 */

// Library Used
#include <Servo.h>
#include <TFT.h>
#include <SPI.h>
#include <avr/pgmspace.h>
#include <EEPROM.h>

// Motor Parameters
#define MOTOR_STEPS 180
#define FOCUS 0
#define ZOOM 1

// Arduino Pins
/* TFT Display Pins */
#define CS  10
#define DC  9
#define RST 12

/* Motor Pins */
#define front_STEP  8
#define rear_STEP   7

/* Joystick Pins */
#define UP    2
#define DOWN  3
#define LEFT  4
#define RIGHT 5
#define SET   6 

/* Camera Control Pins */
#define SHUTTER A5

/* Buzzer Signal Pin */
#define BUZZER A4

// Strings
/* Colour Strings */
#define WHITE     0xFFFF
#define BLACK     0x0000
#define AQUA      0xFEC0
#define DEEPPINK  0xF8B2  
#define DARKGREEN 0x0320
#define RED       0xF800 
#define LIGHTSKYBLUE 0x867F 
#define SNOW 0xFFDF
#define VIOLET 0xEC1D 
#define YELLOWGREEN 0x9E66
#define GOLDENROD 0xF81F
#define AZURE 0xF7FF
#define CORAL 0xFBEA 
#define CADETBLUE 0x5CF4
#define LIME 0x07E0

/* Symbols */
#define UP_ARROW    0x18
#define DOWN_ARROW  0x19
#define RIGHT_ARROW 0x1A
#define LEFT_ARROW  0x1B
#define SELECT      0x2A

/* PRGMEM Bugger */
char buffer[50];

/* Defining Strings */
const char back[] PROGMEM = "Back";

const char mm_0[] PROGMEM = "|---- Main Menu ----|";
const char mm_1[] PROGMEM = "Camera Settings";
const char mm_2[] PROGMEM = "Motor Calibration";
const char mm_3[] PROGMEM = "POV Calibration";
const char mm_4[] PROGMEM = "Focus Movements";
const char mm_5[] PROGMEM = "Zoom Movements";
const char mm_6[] PROGMEM = "ZoomFocus Movements";
const char mm_7[] PROGMEM = "Fixed Patterns";
const char mm_8[] PROGMEM = "Customise Patterns";

const char string_4[] PROGMEM = "|---Calibration---|";
const char string_5[] PROGMEM = "Zoom Calibration";
const char string_6[] PROGMEM = "Focus Calibration";
const char string_7[] PROGMEM = "RESET all values";

const char string_12[] PROGMEM = "|---- Settings -----|";
const char string_13[] PROGMEM = "Swap Motor Position";
const char string_14[] PROGMEM = "Camera Shutter Time";
const char string_15[] PROGMEM = "Motor Movement Time";

const char shutter_menu[] PROGMEM = "|Shutter Time(in s)|";
const char motor_time_menu[] PROGMEM = "Motor Move Time(in s)";

const char string_19[] PROGMEM = "|--Focus Movements--|";
const char string_20[] PROGMEM = "Move to infinity";
const char string_21[] PROGMEM = "Move to min distance";
const char string_22[] PROGMEM = "Move to a Value";
const char string_41[] PROGMEM = "To infinity & back";
const char string_42[] PROGMEM = "To min. & back";
const char string_45[] PROGMEM = "From inf. to POV-min";

const char string_23[] PROGMEM = "|--Zoom Movements --|";
const char string_24[] PROGMEM = "Move to tele";
const char string_25[] PROGMEM = "Move to widest";
const char string_43[] PROGMEM = "To tele & back";
const char string_44[] PROGMEM = "To widest & back";

const char string_27[] PROGMEM = "|Zoom&Focus Movement|";
const char string_28[] PROGMEM = "Move to Max [BOTH]";
const char string_29[] PROGMEM = "Move to Min [BOTH]";
const char string_39[] PROGMEM = "Zoom[MAX]&Focus[MIN]";
const char string_40[] PROGMEM = "Zoom[MIN]&Focus[MAX]";
const char string_46[] PROGMEM = "to Max[BOTH] & back";
const char string_47[] PROGMEM = "to Min[BOTH] & back";
const char string_48[] PROGMEM = "Z[MAX]F[MIN] & back";
const char string_49[] PROGMEM = "Z[MIN]F[MAX] & back";

const char string_31[] PROGMEM = "|----- Presets -----|";
const char string_32[] PROGMEM = "Bokeh Effect";
const char string_33[] PROGMEM = "Firework Effect";
const char string_34[] PROGMEM = "Zoom Blur Effect";
const char string_35[] PROGMEM = "Sine Wave Effect";
const char string_50[] PROGMEM = "ZigZag Zoom Effect";
const char string_51[] PROGMEM = "ZigZag Focus Effect";

const char cali_zoom[] PROGMEM = "|--Calibrate Zoom --|";
const char cali_focus[] PROGMEM = "|--Calibrate Focus--|";
const char string_cali[] PROGMEM = "Move the joystick to \n";
const char zoom_left[] PROGMEM = "the widest lens";
const char zoom_right[] PROGMEM = "the tele lens";
const char focus_left[] PROGMEM = "min. focal length";
const char focus_right[] PROGMEM = "   infinity";

const char adjust_zoom[] PROGMEM = "|--- Adjust Zoom ---|";
const char adjust_focus[] PROGMEM = "|---Adjust Focus ---|";
const char string_36[] PROGMEM = "Adjust [ZOOM] ring";
const char string_36_1[] PROGMEM = "Adjust [FOCUS] ring";
const char string_37[] PROGMEM = "to the desired POV";
const char string_38[] PROGMEM = "to desired Outcome";

const char custom_0[] PROGMEM = "|-CustomisedPattern-|";
const char create_0[] PROGMEM = "Execute Pattern";
const char create_1[] PROGMEM = "Create New Pattern";

const char choose_motor_0[] PROGMEM = "|--Lens Selection--|";
const char choose_motor_1[] PROGMEM = "Move Zoom Lens";
const char choose_motor_2[] PROGMEM = "Move Focus Lens";

const char new_sequence_0[] PROGMEM = "|-Sequence Settings-|";
const char new_sequence_1[] PROGMEM = "Return to origin:false";
const char new_sequence_2[] PROGMEM = "Return to origin:true";
const char new_sequence_3[] PROGMEM = "Add new sequence";

/* String Table */
const char *const main_menu[] PROGMEM = {mm_0, mm_1, mm_2, mm_3, mm_4, mm_5, mm_6, mm_7, mm_8};
const char *const recalibration_menu[] PROGMEM = {string_4, string_5, string_6, string_7, back};
const char *const settings_menu[] PROGMEM = {string_12, string_13, string_14, string_15, back};
//const char *const focus_menu[] PROGMEM = {string_19, string_20, string_21, string_22, string_41, string_42, string_45, back};
//const char *const zoom_menu[] PROGMEM = {string_23, string_24, string_25, string_22, string_43, string_44, back};
//const char *const zoomfocus_menu[] PROGMEM = {string_27, string_28, string_29, string_39, string_40, string_22, string_46, string_47, string_48, string_49, back};
const char *const focus_menu[] PROGMEM = {string_19, string_20, string_21, string_41, string_42, string_45, back};
const char *const zoom_menu[] PROGMEM = {string_23, string_24, string_25, string_43, string_44, back};
const char *const zoomfocus_menu[] PROGMEM = {string_27, string_28, string_29, string_39, string_40, string_46, string_47, string_48, string_49, back};
const char *const presets_menu[] PROGMEM = {string_31, string_32, string_33, string_34, string_35, string_50, string_51, back};
const char *const calizoom_left[] PROGMEM = {cali_zoom, string_cali, zoom_left};
const char *const calizoom_right[] PROGMEM = {cali_zoom, string_cali, zoom_right};
const char *const califocus_left[] PROGMEM = {cali_focus, string_cali, focus_left};
const char *const califocus_right[] PROGMEM = {cali_focus, string_cali, focus_right};
const char *const zoom_adjust[] PROGMEM = {adjust_zoom, string_36, string_37};
const char *const focus_adjust[] PROGMEM = {adjust_focus, string_36_1, string_37};
const char *const focus_dist[] PROGMEM = {string_22, string_36_1, string_38};
const char *const zoom_dist[] PROGMEM = {string_22, string_36, string_38};
//const char *const zoomfocus_dist[] PROGMEM = {string_22, string_36, string_38};
const char *const custom1_emptymenu[] PROGMEM = {custom_0, create_1, back};
const char *const custom1_menu[] PROGMEM = {custom_0, create_0, create_1, back};
const char *const lens_selection_menu[] PROGMEM = {choose_motor_0, choose_motor_1, choose_motor_2, back};
const char *const new_selection_truemenu[] PROGMEM = {new_sequence_0, new_sequence_2, new_sequence_3, back};
const char *const new_selection_falsemenu[] PROGMEM = {new_sequence_0, new_sequence_1, new_sequence_3, back};


// Object Declaration
/* Motor Objects */
Servo rear_motor;
Servo front_motor;

/* Display Object */
TFT tft(CS, DC, RST);

// EEPROM declaration (0-255 int)
/* Things that are saved
 *  - focus_range     (Max range of focus)
 *  - zoom_range      (Max range of zoom)
 *  - focus_current   (Current focus value)
 *  - zoom_current    (Current zoom value)
 *  - orientation     (Orientation of motors)
 *  - shutter_speed   (Shutter speed)
 */
int focus_range;        // address 0
int zoom_range;         // address 1
int focus_current;      // address 2
int zoom_current;       // address 3
int orientation;        // address 4
int shutter_speed;      // address 5
int motor_time;         // address 6
int custom_itemcount1;  // address 8
int focus_min;          // address 9
int zoom_min;           // address 10

// Custom Pattern Variables
char custom_buf1[24];

// Global Variables
int option = 0;
int updateMenu = true;
int screen = -1;    // main screen
int sscreen = -1;   // sub screen
int max_option = 0;

// Function Declaration
int menu(int array_size, const char *const string_table[], int option_selected, int header=0, int footer=2, uint16_t color=DEEPPINK);
void hotbar(char title[], int current, int max_range, int current_option=0, bool haveBack=false, int header=0, int footer=3, uint16_t color=WHITE, bool updateBar=false);
void caliMenu(int type, const char *const string_table[], int current_step, int max_steps=200, uint16_t color=WHITE, bool updateBar=false);
void moveMotorMenu(int count, const char *const string_table[], int current_step, int max_steps, uint16_t color=WHITE, bool updateBar=false);
void updateScreen(float delay_ms=0);
int getUpdate(int s, int offset=0, bool reset=true);
int getUpDown(int option, int current_option, int delay_ms=0);
int getLeftRight(int range, int current, int low_limit=0, int delay_ms=0);
void moveMotor(int type, int pos_desired, int shutter_spd=0);
void moveMultiMotor(int zoom_value, int focus_value, float shutter_spd=0);
int calibrate(int type, const char *const string_table[], int upper_limit, int lower_limit, uint16_t color=WHITE);
int chooseDist(int type, int count, const char *const string_table[], bool goBack=false, uint16_t color=WHITE);
void goDist(int type, char title[], int pos_desired, uint16_t color=WHITE, bool goBack=true, float shutter_spd=motor_time, bool lastSequence=true);
void goMultiDist(char title[], int zoom_desired, int focus_desired, uint16_t color=WHITE, bool goBack=true, float shutter_spd=motor_time, bool lastSequence=true);
void(* resetFunc) (void) = 0;

/* Shutter Function */
void nikonTime() { // Controls the shutter of a Nikon camera
  digitalWrite(SHUTTER, LOW); // close shutter (fully pressed)
  delay(20);
  digitalWrite(SHUTTER, HIGH);
  delay(20);
}

/* Buzzer Function */
void buzz(int delay_ms=500, int freq=1000) {
  tone(BUZZER, freq);   // Send freq(Hz) sound signal...
  delay(delay_ms);      // ...for delay_ms
  noTone(BUZZER);       // Stop sound...
}

/* 
 * ~ SETUP ~
 */
void setup() {
  Serial.begin(9600);

  // **** Buzzer ****
  pinMode(BUZZER, OUTPUT);

  // **** Camera Controls ****
  // set the pins to output pins 
  // Using a Nikon D7100 shutter release
  // and an optocoupler
  // Currently in Time mode (2 presses)
  // HIGH = Open Position, LOW = Close
  pinMode(SHUTTER, OUTPUT);
  
  // ***** Joystick *****
  // change the pinmode for the joystick
  // 0 = pressed, 1 = not pressed
  pinMode(SET, INPUT_PULLUP);
  pinMode(RIGHT, INPUT_PULLUP);
  pinMode(LEFT, INPUT_PULLUP);
  pinMode(DOWN, INPUT_PULLUP);
  pinMode(UP, INPUT_PULLUP);
  
  // ***** Display *****
  // able to call out similar functions
  // in Adafruit GFX lib
  tft.begin();
  tft.setRotation(0);
  tft.background(0,0,0);
  tft.setTextSize(2);

  // This costs 2% (for aesthetic)
  for(int i=0; i<5; i++) { // just to know if initialised properly
    tft.stroke(random(0, 255), random(0, 255), random(0, 255));
    tft.text("MOTOR ICM",6,80);
    delay(200);
  }
  tft.setTextColor(WHITE);
  tft.setTextSize(1);
  tft.background(0,0,0);

  // ***** EEPROM Read *****
  // reads the stored memory
  
  focus_range = EEPROM.read(0);
  zoom_range = EEPROM.read(1);
  focus_current = EEPROM.read(2);
  zoom_current = EEPROM.read(3);
  orientation = EEPROM.read(4);
  shutter_speed = EEPROM.read(5);
  motor_time = EEPROM.read(6);
  custom_itemcount1 = EEPROM.read(8);
  focus_min = EEPROM.read(9);
  zoom_min = EEPROM.read(10);

  // ***** Default Values *****
  // if empty (==255), setting default values to 0
  // for current positions -> Move the motor to stored current 
  if (focus_range == 255) {
    focus_range = 0;
  }
  if (zoom_range == 255) {
    zoom_range = 0;
  }
  if (orientation == 255) {
    orientation = 0;
  }
  if (shutter_speed == 255) {
    shutter_speed = 1;
  }
  if (motor_time == 255) {
    motor_time = 1;
  }
  if (focus_min == 255) {
    focus_min = 5;
  }
  if (zoom_min == 255) {
    zoom_min = 5;
  }
  if (focus_current == 255) {
    focus_current = 0;
  } else if (focus_current != 255) {
    //moveMotor(FOCUS, focus_current);
  }
  if (zoom_current == 255) {
    zoom_current = 0;
  } else if (zoom_current != 255) {
    //moveMotor(ZOOM, zoom_current);
  }

  // For Custom Profiles
  if (custom_itemcount1 == 255) {
    custom_itemcount1 = 0;
  }
  if (custom_itemcount1 > 0) {
    readStringFromMemory(25, custom_buf1);
    Serial.println(custom_buf1);
  }

  // ***** Motor *****
  // attaches servo pin to servo object
  rear_motor.write((orientation ? (focus_current + focus_min) : (zoom_current + zoom_min)) + MOTOR_STEPS);
  front_motor.write(orientation ? (zoom_current + zoom_min) : (focus_current + focus_min));
  rear_motor.attach(rear_STEP);
  front_motor.attach(front_STEP);
}

/*
 * ~ LOOP ~
 */
void loop() {
  switch(screen) {
    /* Camera Settings */
    case 0: {
      switch (sscreen) {
        case 0: {// ** orientation menu **
          orientation = orientation ? 0 : 1;
          EEPROM.write(4,orientation);
          sscreen = -1;
          updateScreen(100);
          break;
        }
        case 1: // ** set shutter time **
          hotbar(shutter_menu, shutter_speed, 40, 0, false, 0, 1, GOLDENROD);
          do {
            hotbar(shutter_menu, shutter_speed, 40, 0, false, 0, 1, GOLDENROD, true);
            shutter_speed = getLeftRight(40, shutter_speed, 0, 0);
          } while(digitalRead(SET));
          EEPROM.write(5, shutter_speed);
          updateScreen(500);
          sscreen = resetScreen(sscreen);
          break;
        case 2: { // ** set motor movement time **
          int shutter_time = 40;
          if (shutter_speed != 0) {
            shutter_time = shutter_speed;
          }
          hotbar(motor_time_menu, motor_time, shutter_time, 0, false, 0, 1, GOLDENROD);
          do {
            hotbar(motor_time_menu, motor_time, shutter_time, 0, false, 0, 1, GOLDENROD, true);
            motor_time = getLeftRight(shutter_time, motor_time, 1);
          } while(digitalRead(SET));
          EEPROM.write(6, motor_time);
          updateScreen(500);
          sscreen = resetScreen(sscreen);
          break;
        }
        case 3: // ** back **
          screen = -1;
          sscreen = -1;
          break;

        default: // [settings menu]
          max_option = menu(4, settings_menu, option, 1);
          sscreen = getUpdate(sscreen);
      }
      break;
    }
    
    /* Recalibration */
    case 1: {
      switch(sscreen) {
        // ** zoom calibration **
        case 0: {
          zoom_min = 0;
          zoom_current = 5;
          moveMotor(ZOOM, zoom_current);
      
          // set to minimum left
          int minZoom = calibrate(ZOOM, calizoom_left, 15, 0, AQUA);
          zoom_min = minZoom;
          zoom_current = 0;
          EEPROM.write(10, zoom_min);
          updateScreen(500);
          
          // set to maximum right
          int maxZoom = calibrate(ZOOM, calizoom_right, MOTOR_STEPS, minZoom, AQUA);
          moveMotor(ZOOM, zoom_min); // returns back to zoom minimum
          zoom_range = maxZoom;
          updateScreen(500);
          EEPROM.write(1, zoom_range);
      
          // minimum becomes absolute min pos
          EEPROM.write(3, zoom_current);
          sscreen = resetScreen(sscreen);
          break;
        }
        
        // ** focus calibration **
        case 1: {
          focus_min = 0;
          focus_current = 5;
          moveMotor(FOCUS, focus_current);
      
          // set to minimum left
          int minFocus = calibrate(FOCUS, califocus_left, 15, 0, DEEPPINK);
          focus_min = minFocus;
          focus_current = 0;
          EEPROM.write(9, focus_min);
          updateScreen(500);
      
          // set to maximum right
          int maxFocus = calibrate(FOCUS, califocus_right, MOTOR_STEPS, minFocus, DEEPPINK);
          moveMotor(FOCUS, focus_min); // returns back to focus minimum
          focus_range = maxFocus; 
          updateScreen(500);
          EEPROM.write(0, focus_range);
      
          // minimum becomes absolute min pos
          EEPROM.write(2, focus_current);
          sscreen = resetScreen(sscreen);
          break;
        }
        
        // ** reset all calibration **
        case 2: {
          // TODO: Add are you sure?
          EEPROM.write(0,255);
          EEPROM.write(1,255);
          EEPROM.write(2,255);
          EEPROM.write(3,255);
          EEPROM.write(9,255);
          EEPROM.write(10,255);
          resetFunc();
          break; 
        }
          
        // ** back **
        case 3:
          screen = -1;
          sscreen = -1;
          break;
        default:
          max_option = menu(4, recalibration_menu, option, -2);
          sscreen = getUpdate(sscreen);
          break;
      }
      break;
    }
    
    /* POV Calibration */
    case 2: {
      updateScreen();
      zoom_current = 0;
      focus_current = 0;
      moveMotor(FOCUS, focus_current);
      moveMotor(ZOOM, zoom_current);
      
      zoom_current = chooseDist(ZOOM, 3, zoom_adjust, false, AQUA);
      EEPROM.write(3, zoom_current);
      updateScreen(500);
      focus_current = chooseDist(FOCUS, 3, focus_adjust, false, DEEPPINK);
      EEPROM.write(2, focus_current);
      updateScreen(500);

      screen = resetScreen(screen);
      break;
    }

    /* Focus Movement */
    case 3: {
      switch(sscreen) { 
        case 0: { // focus to infinity
          countdownMenu();
          goDist(FOCUS, string_20, focus_range, SNOW);
          sscreen = resetScreen(sscreen);
          break;
        }
        case 1: { // focus to min
          countdownMenu();
          goDist(FOCUS, string_21, 0, VIOLET);
          sscreen = resetScreen(sscreen);
          break;
        }
        /*
        case 2: { // focus to dist
          int pos_desired;
          pos_desired = chooseDist(FOCUS, 3, focus_dist, true, YELLOWGREEN);
          updateScreen();
          delay(500);
          countdownMenu();
          goDist(FOCUS, string_22, pos_desired, YELLOWGREEN);
          sscreen = resetScreen(sscreen);
          break;
        } */
        case 2: { // focus to infinity & back
          countdownMenu();
          int previous_pos = focus_current;
          goDist(FOCUS, string_41, focus_range, AZURE, false, motor_time/2, false);
          goDist(FOCUS, string_41, previous_pos, AZURE, false, motor_time/2);
          sscreen = resetScreen(sscreen);
          break;
        }
        case 3: { // focus to min & back
          countdownMenu();
          int previous_pos = focus_current;
          goDist(FOCUS, string_42, 0, CORAL, false, motor_time/2, false);
          goDist(FOCUS, string_42, previous_pos, CORAL, false, motor_time/2);
          sscreen = resetScreen(sscreen);
          break;
        }
        case 4: { // MAX-POV-MIN
          int previous_pos = focus_current;
          printMoveSteps(NULL, string_32, CADETBLUE, 2); // setting lens to starting position
          moveMotor(FOCUS, focus_range);
          focus_current = focus_range;
          countdownMenu();
          goDist(FOCUS, string_45, previous_pos, LIME, false, motor_time/3, false);
          delay(toMS(motor_time/3));
          goDist(FOCUS, string_45, 0, LIME, true, motor_time/3);
          sscreen = resetScreen(sscreen);
          break;
        }
        case 5: { // back
          screen = -1;
          sscreen = -1;
          option = 0;
          break;
        }
        default: {
          max_option = menu(6, focus_menu, option, 0);
          sscreen = getUpdate(sscreen, 0, false);
          break;
        }
      }
      break;
    }
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

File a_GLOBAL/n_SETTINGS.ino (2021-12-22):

// ****** SETTINGS Function ********

void set_Orientation() {
  while (button != 0) {
    option = getUpDown(3, option, 200);
    menu(3, positioning_menu, option);
    getJoyRead();             
  }

  int position_option = option;
  option = 0;
  resetJoy();
  delay(500);

  if (position_option == 0) {
    orientation = 0;
    EEPROM.write(4,orientation);
  }

  if (position_option == 1) {
    orientation = 1;
    EEPROM.write(4,orientation);
  }
  
  goto SETTINGS;
}

void set_ShutterSpeed() {
  if (shutter_speed == 1) {
    option = 0;
  } else if (shutter_speed == 4) {
    option = 1;
  } else if (shutter_speed == 8) {
    option = 2;
  } else if (shutter_speed == 16) {
    option = 3;
  }
  while (button != 0) {
    option = getUpDown(5, option, 200);
    menu(5, shutter_menu, option);
    getJoyRead();
  }

  int shutter_option = option;
  option = 0;
  resetJoy();
  delay(500);

  if (shutter_option == 0) {
    shutter_speed = 1;        
  }
  if (shutter_option == 1) {
    shutter_speed = 4;
  }      
  if (shutter_option == 2) {
    shutter_speed = 8;
  }
  if (shutter_option == 3) {
    shutter_speed = 16;
  }

  EEPROM.write(5, shutter_speed);

  goto SETTINGS;
}

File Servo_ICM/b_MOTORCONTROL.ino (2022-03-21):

/* ******** MOTOR CONTROL Functions **********
 *  
 * Functions involving the stepper driver and movement of motors.
 * Libraries used:
 * - AccelStepper.h
 * 
 * Functions available:
 * calcRPM() - Calculates the RPM required for the motor to move 
 *             to position in a fixed time.
 * calcAccel() - Calculates the acceleration required for the motor to move 
 *               to position in a fixed time.
 * toMS() - Easy seconds to milliseconds converter.
 * splitStr() - Splits a string by ` ` or `,` and works hand in hand with 
 *              `setMotor()` to move a motor based on the string fed.
 * setMotor() - Moves the motor according to the instructions set on the string.
 * moveMotor() - Moves the motor based on the desired position in `x` time.
 * setAccel() - Sets the acceleration of a motor.
 * setCurrentPos() - Sets the current position of a motor.
 * moveMultiMotor() - Moves 2 motors in unison based on the desired position in `x` time.
 * 
 */

/*
 * to MilliSeconds converter
 * 
 * @param seconds   Time to be converted to milliseconds. (in seconds)
 * @return long     Converted seconds to milliseconds.
 */
long toMS(float seconds) {
  return seconds * 1000;
}

/*
 * Using Character Array to Movement
 * - Splits the character array by ` ` or `,`
 * - Gives the required parameters for `setMotor()`
 * 
 * @param data              Character array of the custom pattern.
 * @param title             Title of the screen.
 * @param custom_itemcount  The total amount of sequences in the character array.
 */
void splitStr(char* data, char title[], int custom_itemcount) {
  char int_buf[25];
  strcpy(int_buf, data);
  char* parameter;
  parameter = strtok(int_buf, " ,");
  while (parameter != NULL) {
    setMotor(parameter, title, custom_itemcount);
    parameter = strtok(NULL, " ,");
  }
}

/*
 * Works hand in hand with `splitStr()` to move the motor
 * according to the desired sequence.
 * 
 * How it is read:
 * Z/F T/F T/F int  [min 4 char, max 6 char]
 * data[0] - Either zoom or focus motor.
 * data[1] - If motor has to go back or not.
 * data[2] - If it is the last sequence.
 * data[4++] - The number of steps to move.
 * 
 * @param data              Character array of a sequence/
 * @param title             Title of the screen.
 * @param custom_itemcount  The total amount of sequences in the character array.
 */
void setMotor(char* data, char title[], int custom_itemcount) {
  bool goBack = false;
  if ((data[1] == 'T' || data[1] == 't')) {
    goBack = true;
  }

  bool lastSequence = false;
  if ((data[2] == 'T' || data[2] == 't')) {
    lastSequence = true;
  }
  
  if ((data[0] == 'F') || (data[0] == 'f')) {
    int steps = strtol(data+3, NULL, 10);
    // set focus motor steps to steps
    //moveMotor(FOCUS, steps, motor_time/custom_itemcount);
    goDist(FOCUS, title, steps, SNOW, goBack, motor_time/custom_itemcount, lastSequence); 
  }

  if ((data[0] == 'Z') || (data[0] == 'z')) {
    int steps = strtol(data+3, NULL, 10);
    // set zoom motor steps to steps
    //moveMotor(ZOOM, steps, motor_time/custom_itemcount);
    goDist(ZOOM, title, steps, AZURE, goBack, motor_time/custom_itemcount, lastSequence);
  }
}

/*
 * Move motor to desired location
 * - Given the position
 * - Move the motor to pos
 * - Return motor to pos
 * type = 0 [FOCUS], 1 [ZOOM]
 *  orientation 0 [Focus Front, Zoom Rear]
 *  orientation 1 [Zoom Front, Focus Rear]
 *  
 * @param type          Motor currently selected.
 * @param pos_desired   Number of steps for the motor to move.
 * @param shutter_spd   Time allowed for the motor to move to the desired position.
 */

void moveMotor(int type, int pos_desired, int shutter_spd=0) {
  // zoom_range, focus_range, zoom_current, focus_current, 
  // zoom_min, focus_min, shutter_speed
  Servo *motor;
  int pos_current;
  int min_pos;
  
  if (type) { // ZOOM
    motor = orientation ? &front_motor : &rear_motor;
    pos_current = zoom_current;
    min_pos = zoom_min;
  } else { // FOCUS
    motor = orientation ? &rear_motor : &front_motor;
    pos_current = focus_current;
    min_pos = focus_min;
  }

  int steps_to_move = (pos_desired - pos_current);
  
  // if +ve, move clockwise
  // else -ve, move anti-clockwise
  if (shutter_spd != 0) {
    if (steps_to_move > 0) {  // +ve
      for (int pos=pos_current; pos<=pos_desired; pos+=1) {
        if ((type == 1 && orientation == 0) || (type == 0 && orientation == 1)) { // if rear motor
          motor->write(MOTOR_STEPS - (pos + min_pos));
        } else {
          motor->write(pos + min_pos);
        }
        delay(toMS((float)shutter_spd/abs(steps_to_move)));
      }
    }

    if (steps_to_move < 0) {  // -ve
      for (int pos=pos_current; pos>=pos_desired; pos-=1) {
        if ((type == 1 && orientation == 0) || (type == 0 && orientation == 1)) { // if rear motor
          motor->write(MOTOR_STEPS - (pos + min_pos));
        } else {
          motor->write(pos + min_pos);
        }
        delay(toMS((float)shutter_spd/abs(steps_to_move)));
      }
    }
    
  } else {
    if ((type == 1 && orientation == 0) || (type == 0 && orientation == 1)) { // if rear motor
      motor->write(MOTOR_STEPS - (pos_desired + min_pos));
    } else {
      motor->write(pos_desired + min_pos);
    }
  }

  type ? zoom_current = pos_desired : focus_current = pos_desired;
}
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

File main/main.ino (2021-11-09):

#include <A4988.h>
#include <Adafruit_GFX.h>
#include <Adafruit_SSD1306.h>
#include <avr/pgmspace.h>
#include <EEPROM.h>

// for debugging
bool debug = false;

// defining OLED display
#define SCREEN_WIDTH 128
#define SCREEN_HEIGHT 64
#define OLED_RESET -1
#define SCREEN_ADDRESS 0x3C
#define WHITE SSD1306_WHITE
#define BLACK SSD1306_BLACK

// using a 200-step motor
#define MOTOR_STEPS 200

// RPM
#define RPM 120

// Arduino Pins
/* Motor Pins */
#define rear_DIR 3
#define rear_STEP 4
#define front_DIR 5
#define front_STEP 6

/* Joystick Pins */
#define VRX A0
#define VRY A1
#define SW 12

/* PRGMEM Buffer */
char buffer[50];

/* defining strings */
const char back[] PROGMEM = "Back";
const char range[] PROGMEM = "\nRange:  ";
const char joystick_0[] PROGMEM = "Use the joystick for controls";
const char joystick_1[] PROGMEM = "Move joystick left and right to adjust the turn.";
const char joystick_2[] PROGMEM = "Click joystick to cfm";
const char set_txt[] PROGMEM = "Set";
const char steps_txt[] PROGMEM = "Steps to move: ";
const char blank_txt[] PROGMEM = " ";

const char string_0[] PROGMEM = "|---- Main Menu ----|";
const char string_1[] PROGMEM = "Calibration";
const char string_2[] PROGMEM = "Basic Movements";
const char string_3[] PROGMEM = "Advanced Movements";
const char string_3_1[] PROGMEM = "Settings";

const char string_4[] PROGMEM = "|---Recalibration---|";
const char string_5[] PROGMEM = "Zoom Recalibration";
const char string_6[] PROGMEM = "Focus Recalibration";
const char string_7[] PROGMEM = "RESET all values";

const char string_8[] PROGMEM = "|---Basic Movement--|";
const char string_9[] PROGMEM = "Manual Zoom";
const char string_10[] PROGMEM = "Manual Focus";
const char string_11[] PROGMEM = "Zoom to fixed Dist.";

const char string_12[] PROGMEM = "|-Move to distance--|";
const char string_13[] PROGMEM = "Zoom to Max";
const char string_14[] PROGMEM = "Zoom to Min";
const char string_15[] PROGMEM = "Zoom to a distance";

const char string_16[] PROGMEM = "|-Advance Movement--|";
const char string_17[] PROGMEM = "Bokeh Effect";
const char string_18[] PROGMEM = "Firework Effect";
const char string_19[] PROGMEM = "Zoom Blur Effect";
const char string_20[] PROGMEM = "Sine Wave Effect";

const char string_21[] PROGMEM = "Set the ring \nto focus on \na subject";
const char string_22[] PROGMEM = "Set the ring \nas blur as \npossible";
const char string_23[] PROGMEM = "You are setting \nthe maximum turn \nfor zoom ring.";
const char string_24[] PROGMEM = "You are setting \nthe mininum turn \nfor zoom ring.";

const char string_25[] PROGMEM = "|---- Settings -----|";
const char string_26[] PROGMEM = "Zoom/Focus Position";
const char string_27[] PROGMEM = "Camera Shutter Speed";

const char string_28[] PROGMEM = "|----Positioning----|";
const char string_29[] PROGMEM = "Zoom at the back";
const char string_30[] PROGMEM = "Zoom at the front";

const char string_31[] PROGMEM = "|---Shutter Speed---|";
const char string_32[] PROGMEM = "1s";
const char string_33[] PROGMEM = "4s";
const char string_34[] PROGMEM = "8s";
const char string_35[] PROGMEM = "16s";

/* Setting up string table */
const char *const main_menu[] PROGMEM = {string_0, string_1, string_2, string_3, string_3_1};
const char *const recalibration_menu[] PROGMEM {string_4, string_5, string_6, string_7, back};
const char *const basic_menu[] PROGMEM = {string_8, string_9, string_10, string_11, back};
const char *const movetodist_menu[] PROGMEM = {string_12, string_13, string_14, string_15, back};
const char *const adv_menu[] PROGMEM = {string_16, string_17, string_18, string_19, string_20, back};
const char *const key_phrases[] PROGMEM = {back, range, set_txt, steps_txt, blank_txt};
const char *const ring_phrases[] PROGMEM = {string_21, string_22, string_23, string_24};
const char *const joystick_phrases[] PROGMEM = {joystick_0, joystick_1, joystick_2};
const char *const settings_menu[] PROGMEM = {string_25, string_26, string_27, back};
const char *const positioning_menu[] PROGMEM = {string_28, string_29, string_30, back};
const char *const shutter_menu[] PROGMEM = {string_31, string_32, string_33, string_34, string_35, back};


// A4988 stepper(MOTOR_STEPS, DIR, STEP, MS1, MS2, MS3)
// focus ring is infront compared to zoom ring
// motor objects
A4988 rear_motor(MOTOR_STEPS, rear_DIR, rear_STEP);
A4988 front_motor(MOTOR_STEPS, front_DIR, front_STEP);

// Joystick joy(VRX, VRY, SW)
// creating Joystick object
/* will be done when cleaning up code */

// display object
Adafruit_SSD1306 display(SCREEN_WIDTH, SCREEN_HEIGHT, &Wire, OLED_RESET);

// EEPROM declaration (0-255 int)
/* Things that are saved
 *  - diff_focus    (Max range of focus)
 *  - diff_zoom     (Max range of zoom)
 *  - focus_min     (Last focus call)
 *  - zoom_min      (Last zoom call)
 */
int focus_min;      // address 0
int zoom_min;       // address 1
int diff_focus;     // address 2
int diff_zoom;      // address 3
int orientation;    // address 4
int shutter_data;   // address 5

// variable declaration
int value = 0;    // debug value
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

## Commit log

2021-08-17 Update main.ino
    Fix a bit of bugs
    -> Change rotate to move
    -> Added a goto (Not recommended till I clean up the code)
    TODO:
    Clean up the code, reduce total size
    [main.ino]
2021-11-02 Update main.ino
    + reverted back the calibration
    + change the way the motor works
    [main.ino]
2021-11-02 Update main.ino
    fixed the rest of the program
    [main.ino]
2021-12-14 A bunch of stuff + fixes
    [Motor_ICM.ino, a_DISPLAY.ino, b_MOTORCONTROL.ino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]
2021-12-20 Fixes Calibration
    - Added an easier way to do calibration
    - Should be more reliable
    - Fixes #5
    [Motor_ICM.ino, b_MOTORCONTROL.ino, d_INTERFACE.ino]
2021-12-20 Start the fix for individual motor movements
    Will be very helpful in the long run
    [Motor_ICM.ino, d_INTERFACE.ino]
2021-12-21 Fully migrated to new methods
    +Fixes bugs that were in the code
    [Motor_ICM.ino, a_DISPLAY.ino, d_INTERFACE.ino]
2021-12-22 Update Motor_ICM.ino
    Added a go to specific distance
2021-12-22 Update Motor_ICM.ino
    Felt that the acceleration was too slow
    [Motor_ICM.ino]
2021-12-22 Update Motor_ICM.ino
    Changed some strings
2021-12-22 Update Motor_ICM.ino
    Readded back the firstTime menu before navigation. Also added EEPROM save functionality
2021-12-22 Update Motor_ICM.ino
    Some cleanup and bug fixes
    [Motor_ICM.ino]
2021-12-22 Fixes some display bug
    [a_DISPLAY.ino]
2021-12-22 Fixed some shutter speed bugs
    [Motor_ICM.ino]
2021-12-22 Fixed no text bug
    [a_DISPLAY.ino]
2021-12-22 Bug Squashing done
    I am proud of this one son
    [Motor_ICM.ino, d_INTERFACE.ino]
2021-12-22 Makes finer adjustments to calibration
2021-12-22 added missing string in menu
    [Motor_ICM.ino]
2021-12-22 Forgot to times the micro steps
    This causes the motor to move by itself when selecting to desired image
2021-12-22 Some debugging
    Fixed issue of infinite loop
    Clean up some code at line 571
    [Motor_ICM.ino]
2021-12-25 Change the calibration method
    min then max.
    Range for min: 100 steps left or right
    Range for max: 200 steps
2021-12-25 Added POV calibration to setup
    If it has been reset fully, setup will ask to adjust the POV calibration. Currently in KIV, will remove if necessary. Further adjustments can be made in POV calibration in the now revamped menu
    [Motor_ICM.ino]
2021-12-25 Change the main menu & subsequent menus
    Main Menu now has 8 options:
    [0] Camera Settings
    [1] Motor Calibration
    [2] POV Calibration
    [3] Focus Movements
    [4] Zoom Movements
    [5] ZoomFocus Movements
    [6] Fixed Patterns
    [7] Customise Patterns
    6 & 7 are not working currently. Will be worked on in the upcoming week.
    * Main Menu now do not have any headers to reduce the space requirement. (Will need to see if it is possible to be added in)
    [Motor_ICM.ino, a_DISPLAY.ino]
2021-12-25 Changing delay and text in countdown
    Felt that the delay was too long. Hence from 5s changed it to 2s instead before the timer starts counting down. Also fixed a bug of screen not clearing when printing the timer down
    [a_DISPLAY.ino]
2021-12-25 Fixed missing bracket
2021-12-25 Added the missing goBack feature in the interface
    This allows the interface to be used again and again without moving back to original spot everytime
    [Motor_ICM.ino, d_INTERFACE.ino]
2021-12-25 Missing goBack in the main file
    Will cause an error without it
    [Motor_ICM.ino]
2021-12-25 Added camera pins to interface with shutter release
    Currently using on a Nikon D7100 shutter release with a dual relay module. Also, camera is adjusted to Time mode
    => Requires 2 shutter presses. 1 to start long exposure, 1 to end.
2021-12-28 Missing ;
    Forgot to compile to check for errors.
    [d_INTERFACE.ino]
2021-12-28 Missing return to 0
    Added a movemotor for the motor to go back to default 0
    [Motor_ICM.ino]
2021-12-28 Fixes some issues
    Fix calibration error
    Maybe fixes joystick movements?
    [Motor_ICM.ino]
2022-01-02 Added missing POV calibration
    [Motor_ICM.ino]
2022-01-02 Fix small type resulting in no shutter speed display
    [a_DISPLAY.ino]
2022-01-02 Calibration string changes
    - extreme left & right
    + zoom => widest to tele
    + focus => min. to infinity
2022-01-02 Update calibration string
    Makes it sound more pleasant
2022-01-02 Remove setup menu
    !! WARNING !!
    Currently experimental. I find that it's redundant first of all & secondly, it will cause a lot of issue. Hence, removing this entirely is the best course of action
    Remove clearing of shutter_speed and orientation in reset all
    [Motor_ICM.ino]
2022-01-02 Calibration Changes
    + Changed calibration works to be like the ones setup used to be min->max
    + Added a new footer for the 2 directions for both zoom and focal lens
2022-01-02 Update to POV Calibration
    +Sets the motors to zero
2022-01-02 Added missing 'break'
    Fixed causing screen issues
    [Motor_ICM.ino]
2022-01-05 Added a delay in between movements
    Fixes #17
    [b_MOTORCONTROL.ino]
2022-01-10 Fixes #19
    Added adjustable motor time
    [Motor_ICM.ino]
2022-01-10 Updated interfaces to use motor_time by default instead of shutter_speed/2
    Fixes #19
    [d_INTERFACE.ino]
2022-01-10 Added a display to see the motor time being set
    Refer to #19 . Continued from PR #20
2022-01-10 Adjusted the rect coordinates & more distinct headers
    Added a -2 to print only a certain case
2022-01-10 Start of multistepper fixes
    Links to #18
    [b_MOTORCONTROL.ino]
2022-01-10 Minor Fixes
    - Some changes to texts
    - Some changes to Calibration Menu
    [Motor_ICM.ino, a_DISPLAY.ino]
2022-01-10 Fixes the multistepper
    Fix #18
    [NOTE] The multistepper function still requires a fix to timing issue as mentioned in #21
    [Motor_ICM.ino, a_DISPLAY.ino, b_MOTORCONTROL.ino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]
2022-01-11 Started working on Fixed Patterns
    [a_DISPLAY.ino]
2022-01-13 Bug Fixes
    * Fixes some typo
    Addressed the bug which results in inconsistent Motor Movements when shutter speed was not included in function.
    Fixes #29
    [Motor_ICM.ino, b_MOTORCONTROL.ino]
2022-01-13 Added new customised patterns features
    Patrons will be able to customise patterns to their likings. However, only 1 Movement type allowed. MultiMotor movement not supported yet (Since got issue with the timings) #26
    [Motor_ICM.ino, b_MOTORCONTROL.ino, c_JOYSTICK.ino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]
2022-01-13 Bug Fixes & Cleanups
    Some Fixes and Parity Issues
    [Motor_ICM.ino, b_MOTORCONTROL.ino, d_INTERFACE.ino]
2022-01-14 Fix the MultiStepper movement bug
    Time Taken currently not the best. About 24s when it puts 16s.
    [b_MOTORCONTROL.ino, d_INTERFACE.ino]
2022-01-14 Remove Serial Prints
    Only used for Debugging
2022-01-19 Fixes #28
    Camera Shutter module has been added
    [Motor_ICM.ino]
2022-01-19 Fixes #36
    The display was not updated dynamically due to updateMenu being false. Should update the screen now and display correctly
    [Motor_ICM.ino]
2022-01-19 Fixes #38
    Just a small string change
    [Motor_ICM.ino]
2022-01-20 Added the buzzer module
    Defaults to 500ms and 1kHz sound signal
    Fixes #41
    [Motor_ICM.ino, d_INTERFACE.ino]
2022-01-20 Removed the delay between sequences
    Moved the delay to only have it during returning to original spot.
    Fixes #46
    [d_INTERFACE.ino]
2022-01-20 Maybe fixes shutter and buzzer going off at the wrong sequence?
    May fix #47
    [Motor_ICM.ino, a_DISPLAY.ino, d_INTERFACE.ino]
2022-01-20 Remove setting option back to 0
    Fixes #44
    [a_DISPLAY.ino]
2022-01-20 Ignores countdown if shutter time is 0
    Added back the delays for consistency. Moved nikonTime function further up, supposed to be before exposing camera to environment
    Addresses #40
2022-01-20 Added new Max-POV-Min
    start from infinity first, go to POV location (and stay a short while), then move to the shortest distance
    [Motor_ICM.ino, a_DISPLAY.ino]
2022-01-20 Added new zoom/focus features
    Max & Back
    Min & Back
    MaxMin & Back
    MinMax & Back
    Fixes #43
    [Motor_ICM.ino]
2022-01-20 Added ZigZag feature
    Fixes #42
    [Motor_ICM.ino, b_MOTORCONTROL.ino]
2022-01-23 Bug Fixes and Some Changes
    ZigZag now from POV to Tele.
    Fixes header not updating in SWAP (Now that I think about it, it's the same)
    Remembers the just completed move?
    [Motor_ICM.ino, a_DISPLAY.ino, c_JOYSTICK.ino]
2022-02-12 Started on Servo ICM Project
    This is part 2 of my FYP
2022-02-12 Started change library to use Servo.h
    Library used for servo motors
2022-02-15 Fully updated the methods
    Shifts to Servo.h library
2022-02-17 Bigger T-Slot
    [NEW_MotorMount.scad]
2022-02-17 Updated the T-Slot
    [servo_mount.scad]
2022-02-21 Added a minimum
    + Realise a problem with current implementation. Problem being that the signal cannot be flipped as of currently. May need to do some tweaking to code. Otherwise, should work flawlessly
    [Servo_ICM.ino, b_MOTORCONTROL.ino, d_INTERFACE.ino]
2022-02-23 Flipped rear motor
2022-03-02 Reverted back some stuff
    [b_MOTORCONTROL.ino, d_INTERFACE.ino]
2022-03-02 Added the missing steps
    When no shutter speed is available...
    [b_MOTORCONTROL.ino]
2022-03-02 Move setting up of servo further down
    Helps to prevent the servo from always starting at 90*
    [Servo_ICM.ino]
2022-03-02 Fix calibration issues
    Should fix the calibration issues it was having
    [Servo_ICM.ino]
2022-03-02 Revert "Testing code"
    This reverts commit 7ef3ac90c615ea9ff91437ff574dca844708d24b.
    [d_INTERFACE.ino]
2022-03-06 Fix to infinite looping occuring
    [b_MOTORCONTROL.ino]
2022-03-17 Added gears library
    This thing was created by Thingiverse user eleotlecram, and is licensed under cc-nc-sa.
    [gears.scad]
2022-03-20 Added documentation & images
    [gantt chart.xlsx]
2022-03-21 Changes to file structure
    [NEW_MotorMount.scad, OpenBeamMotorMount.scad, base_mount_biggerTslot_Front.stl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]
2022-03-21 Fixed some bugs and crashes
    [a_DISPLAY.ino, b_MOTORCONTROL.ino]
2022-03-21 Fixed a bug that causes the crash
    [Servo_ICM.ino, b_MOTORCONTROL.ino]

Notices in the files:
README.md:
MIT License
